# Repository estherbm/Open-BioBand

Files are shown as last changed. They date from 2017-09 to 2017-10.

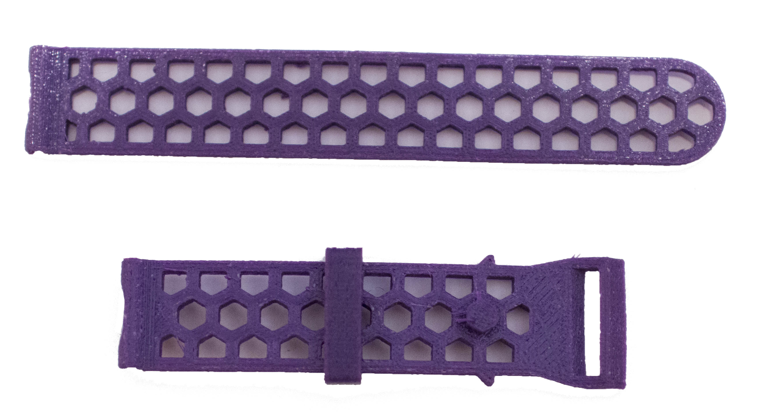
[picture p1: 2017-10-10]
Images/Testing/3.jpg

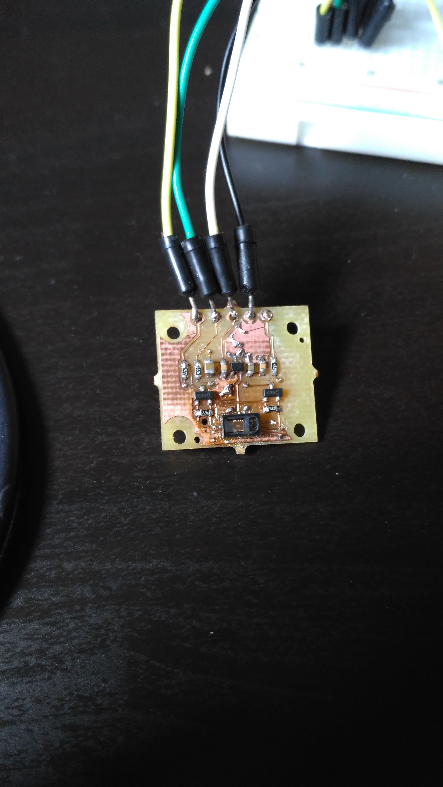
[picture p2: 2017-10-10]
Images/Testing/MAX30101.jpeg

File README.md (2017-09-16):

# Open-BioBand

    Open BioBand is a biometric Open Source wristband with BLE (Bluetooth
    Low Energy) connectivity used to non-invasive monitorization of patients
    and their environment. It measure several parameters such as pulse, SPO2,
    body temperature, motion activity, pressure, humidity, temperature...

    It allow developers to investigate and learn about wearables and biometric 
    sensors and artists to create new biological performances and projects.
    
    Created as final thesis Industrial Engineering project.

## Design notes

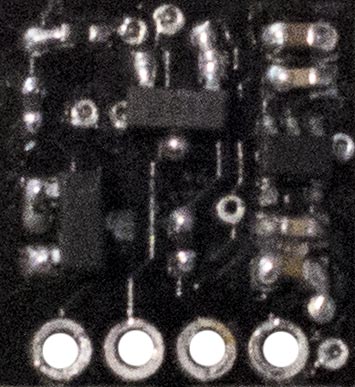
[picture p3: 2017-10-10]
Images/PCBs/MAX30101-B.jpg

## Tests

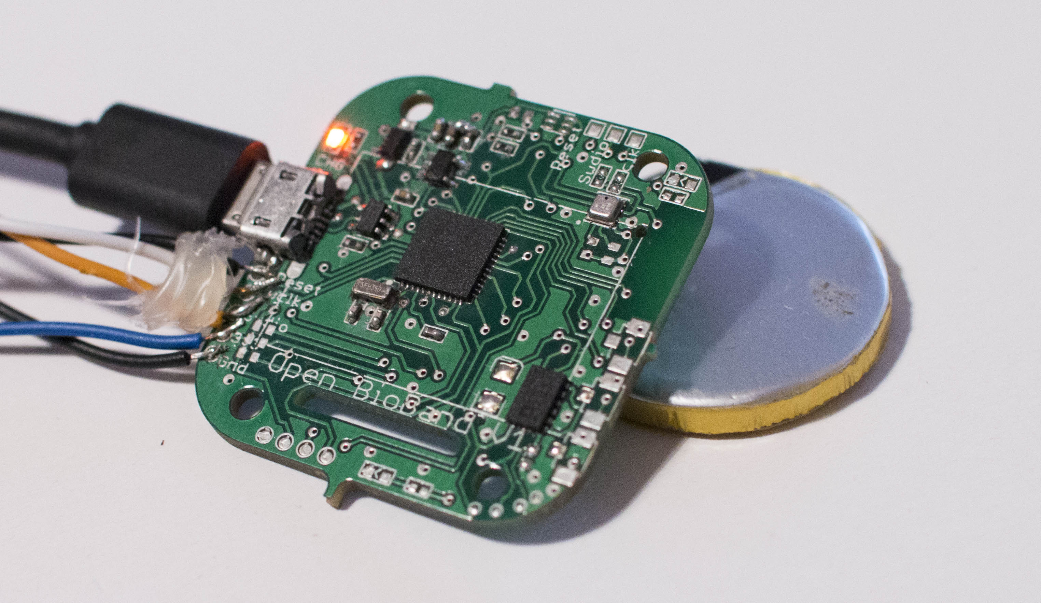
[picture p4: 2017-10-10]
Images/Testing/USBcharging.jpg

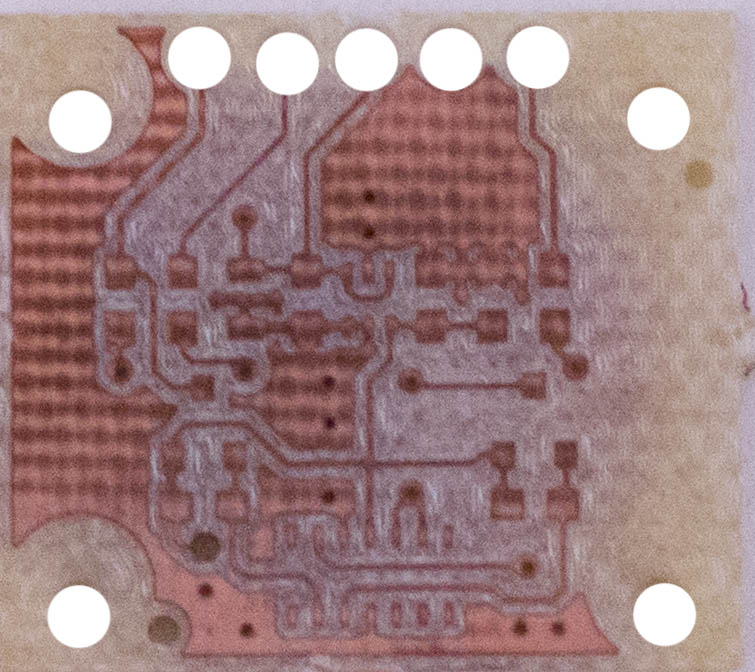
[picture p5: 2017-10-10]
Images/Testing/MAX30101-B_test.jpg

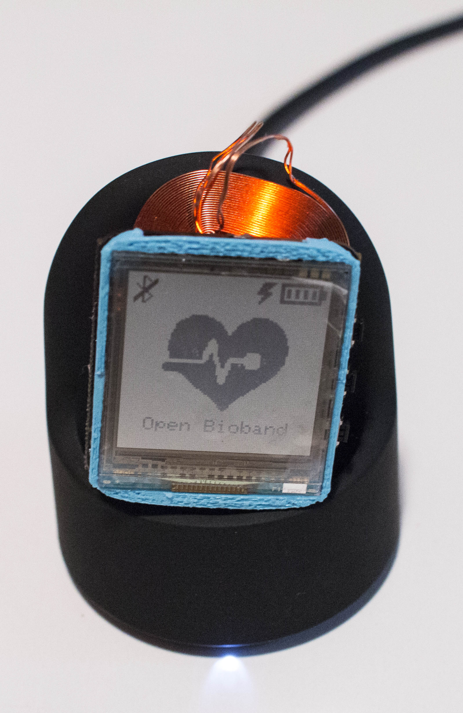
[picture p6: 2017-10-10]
Images/Testing/QiCharging.jpg

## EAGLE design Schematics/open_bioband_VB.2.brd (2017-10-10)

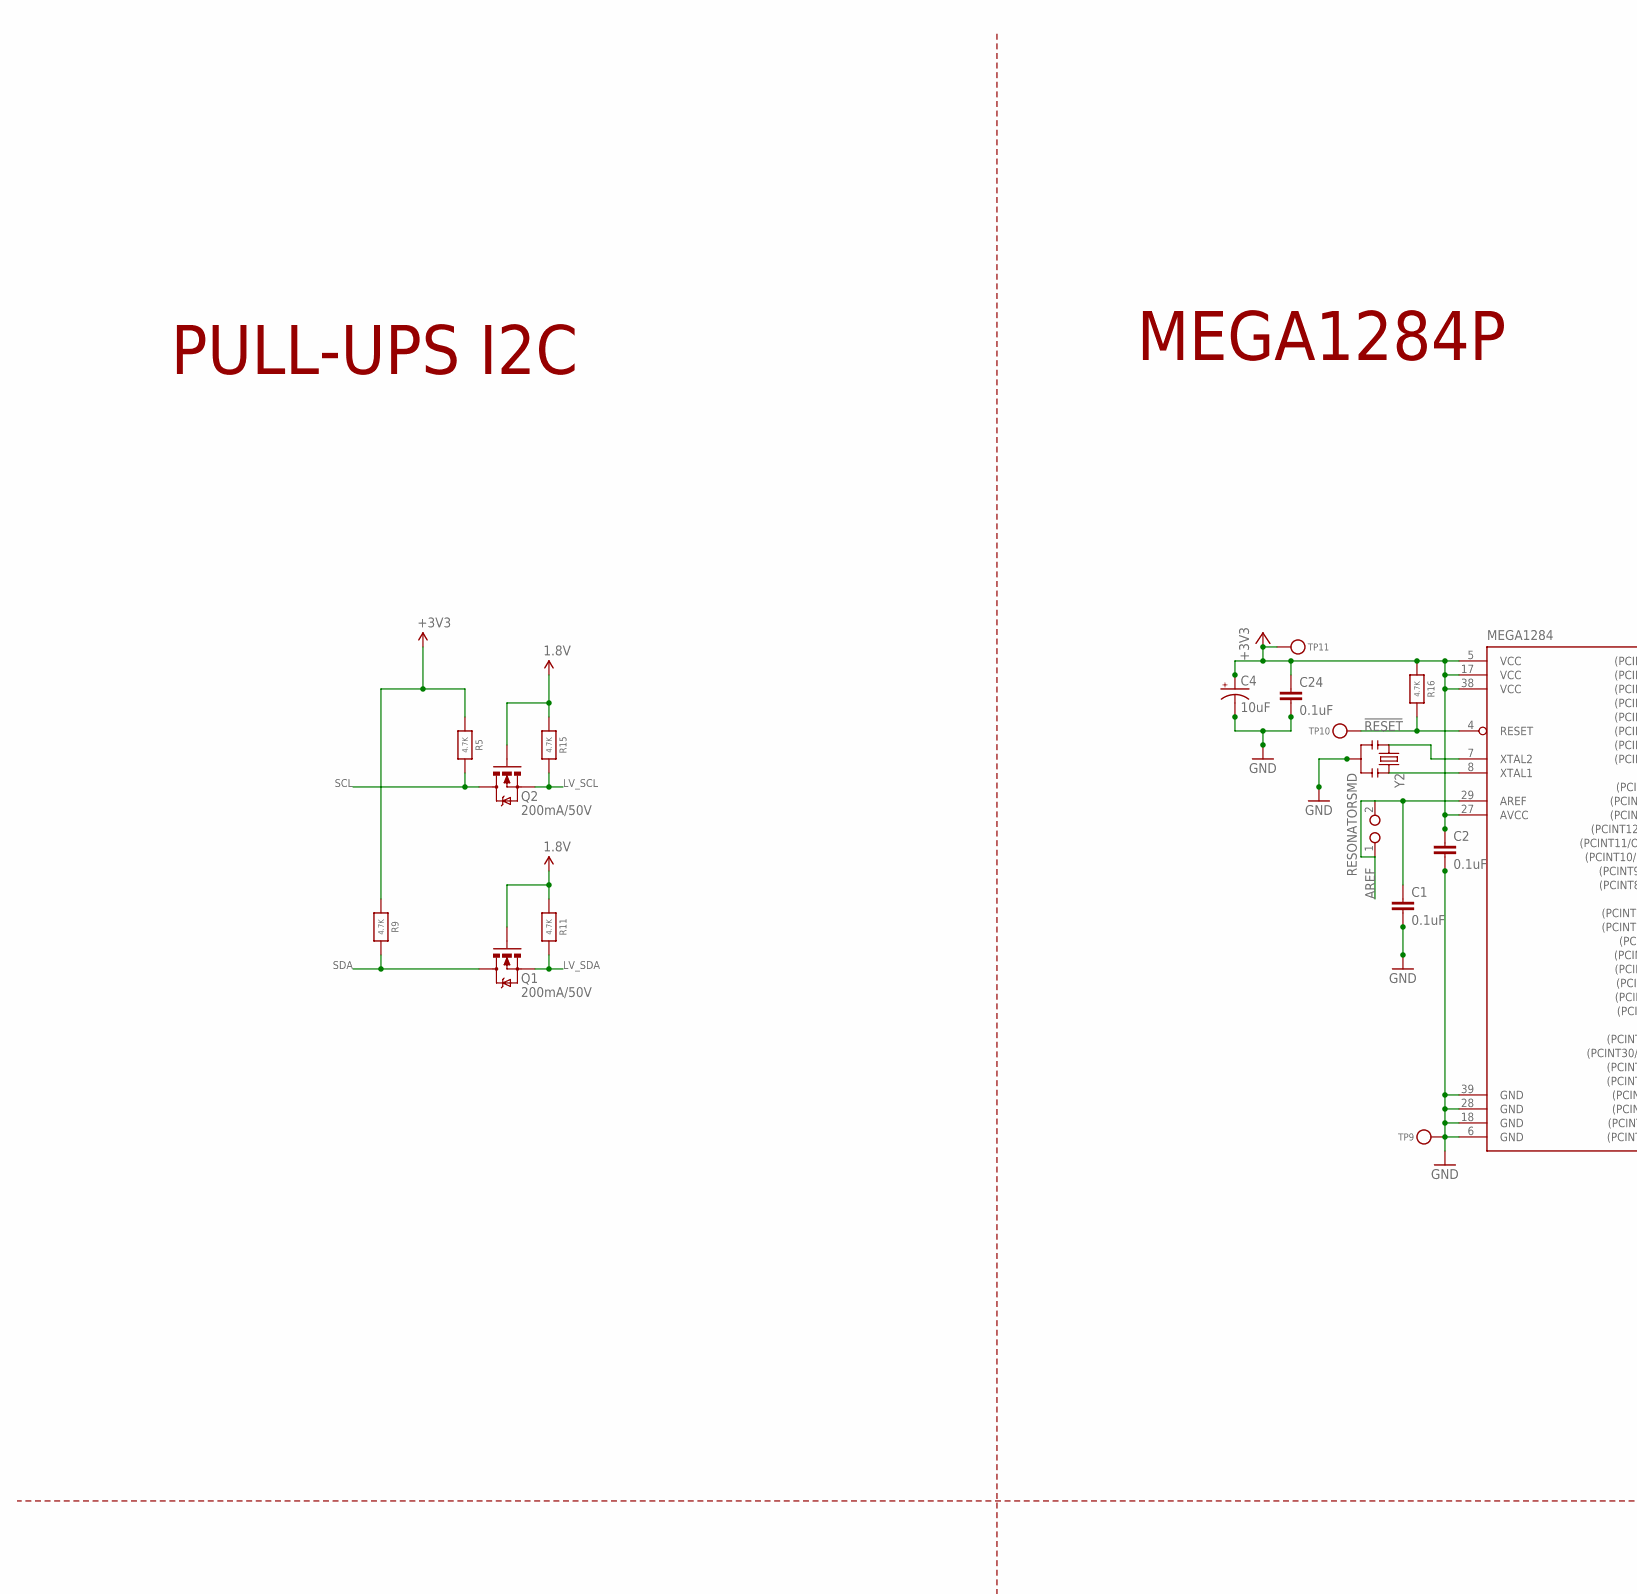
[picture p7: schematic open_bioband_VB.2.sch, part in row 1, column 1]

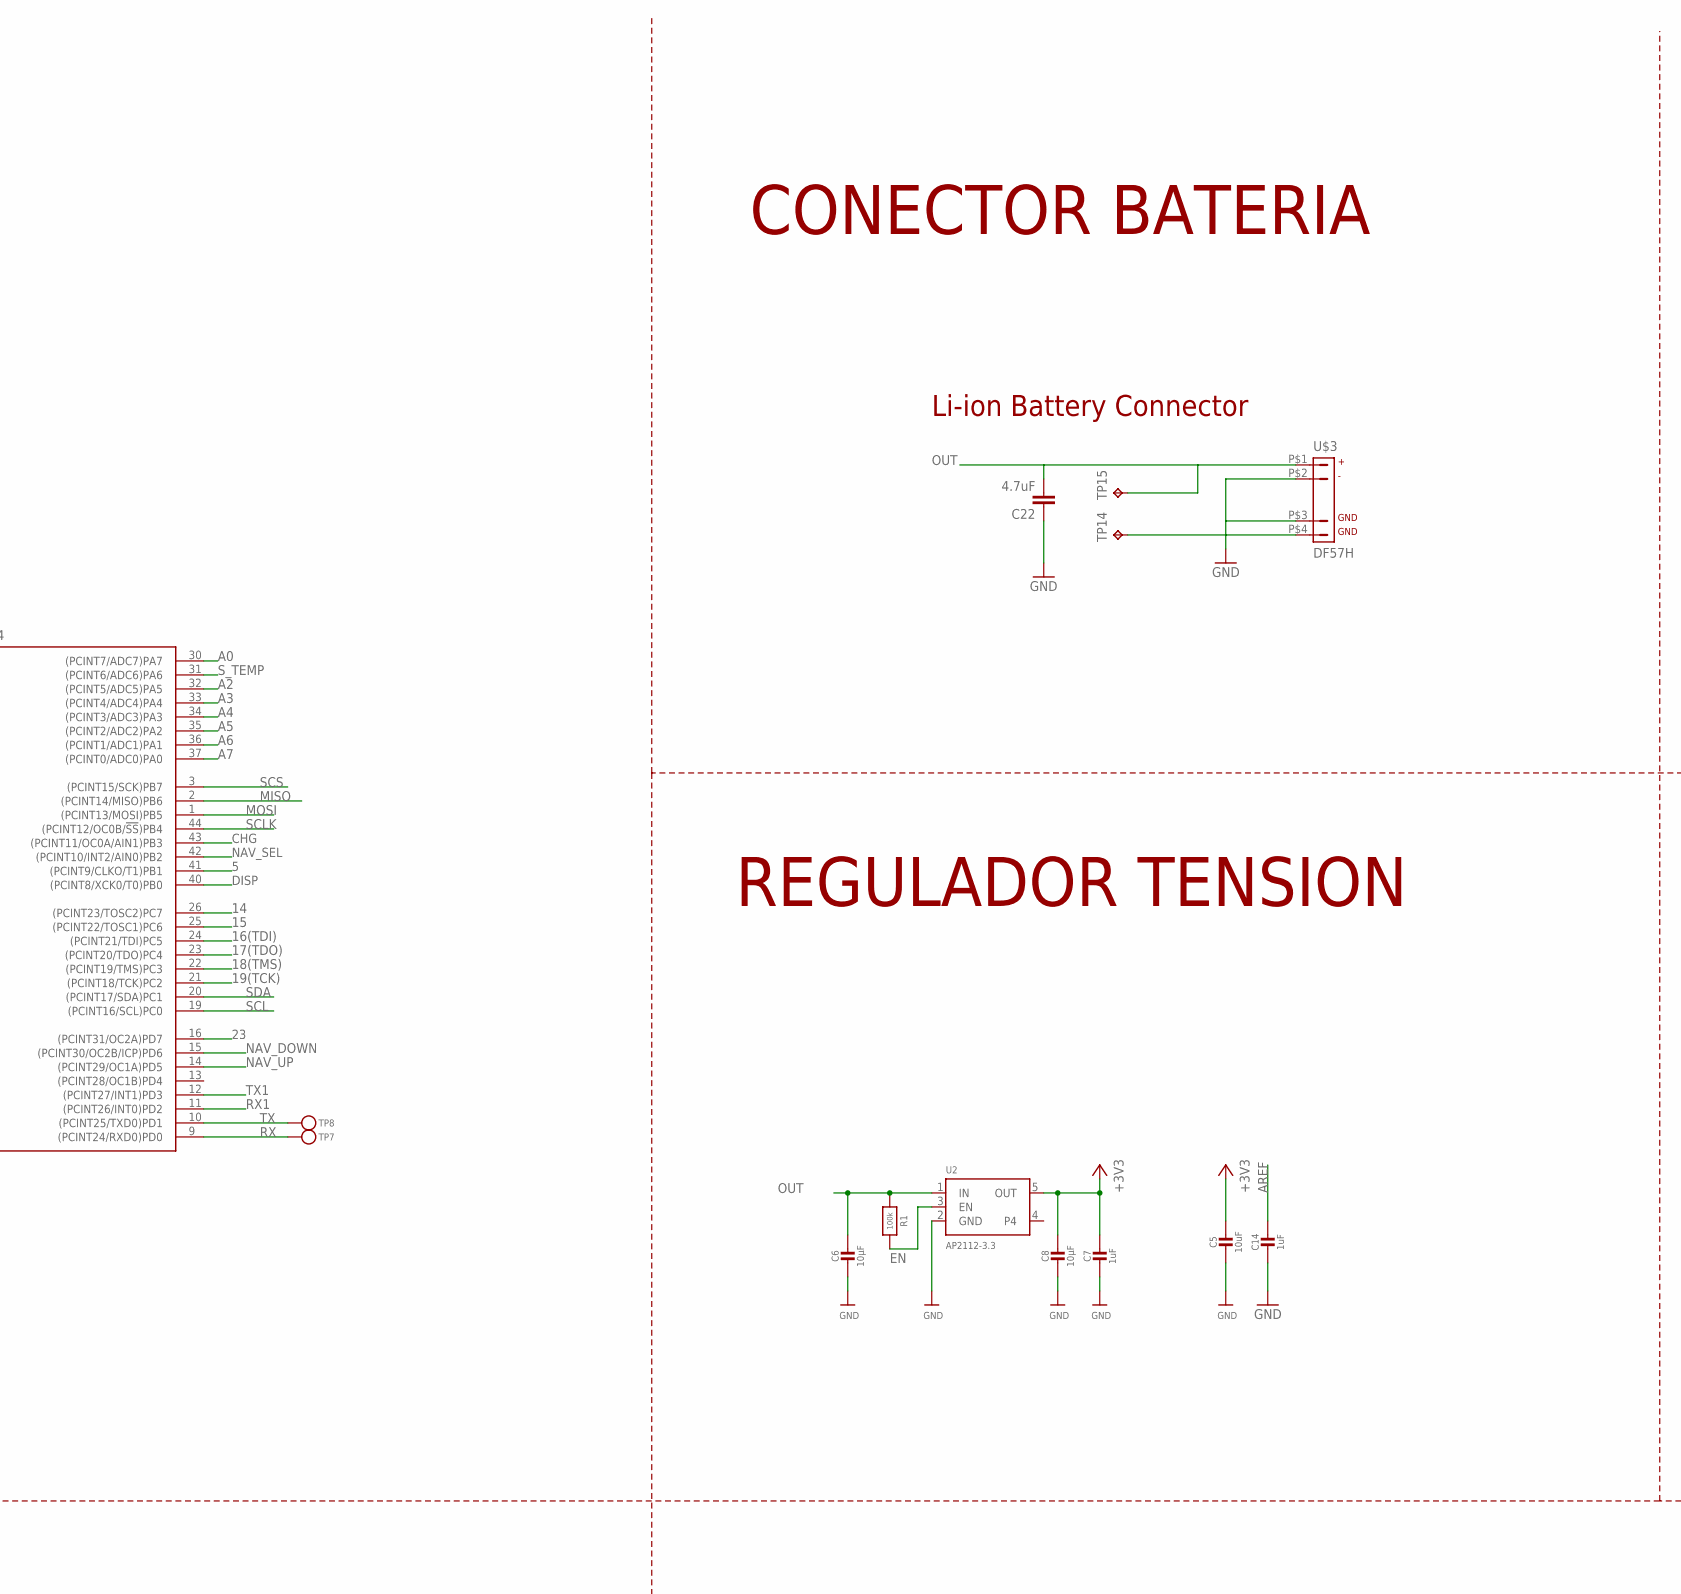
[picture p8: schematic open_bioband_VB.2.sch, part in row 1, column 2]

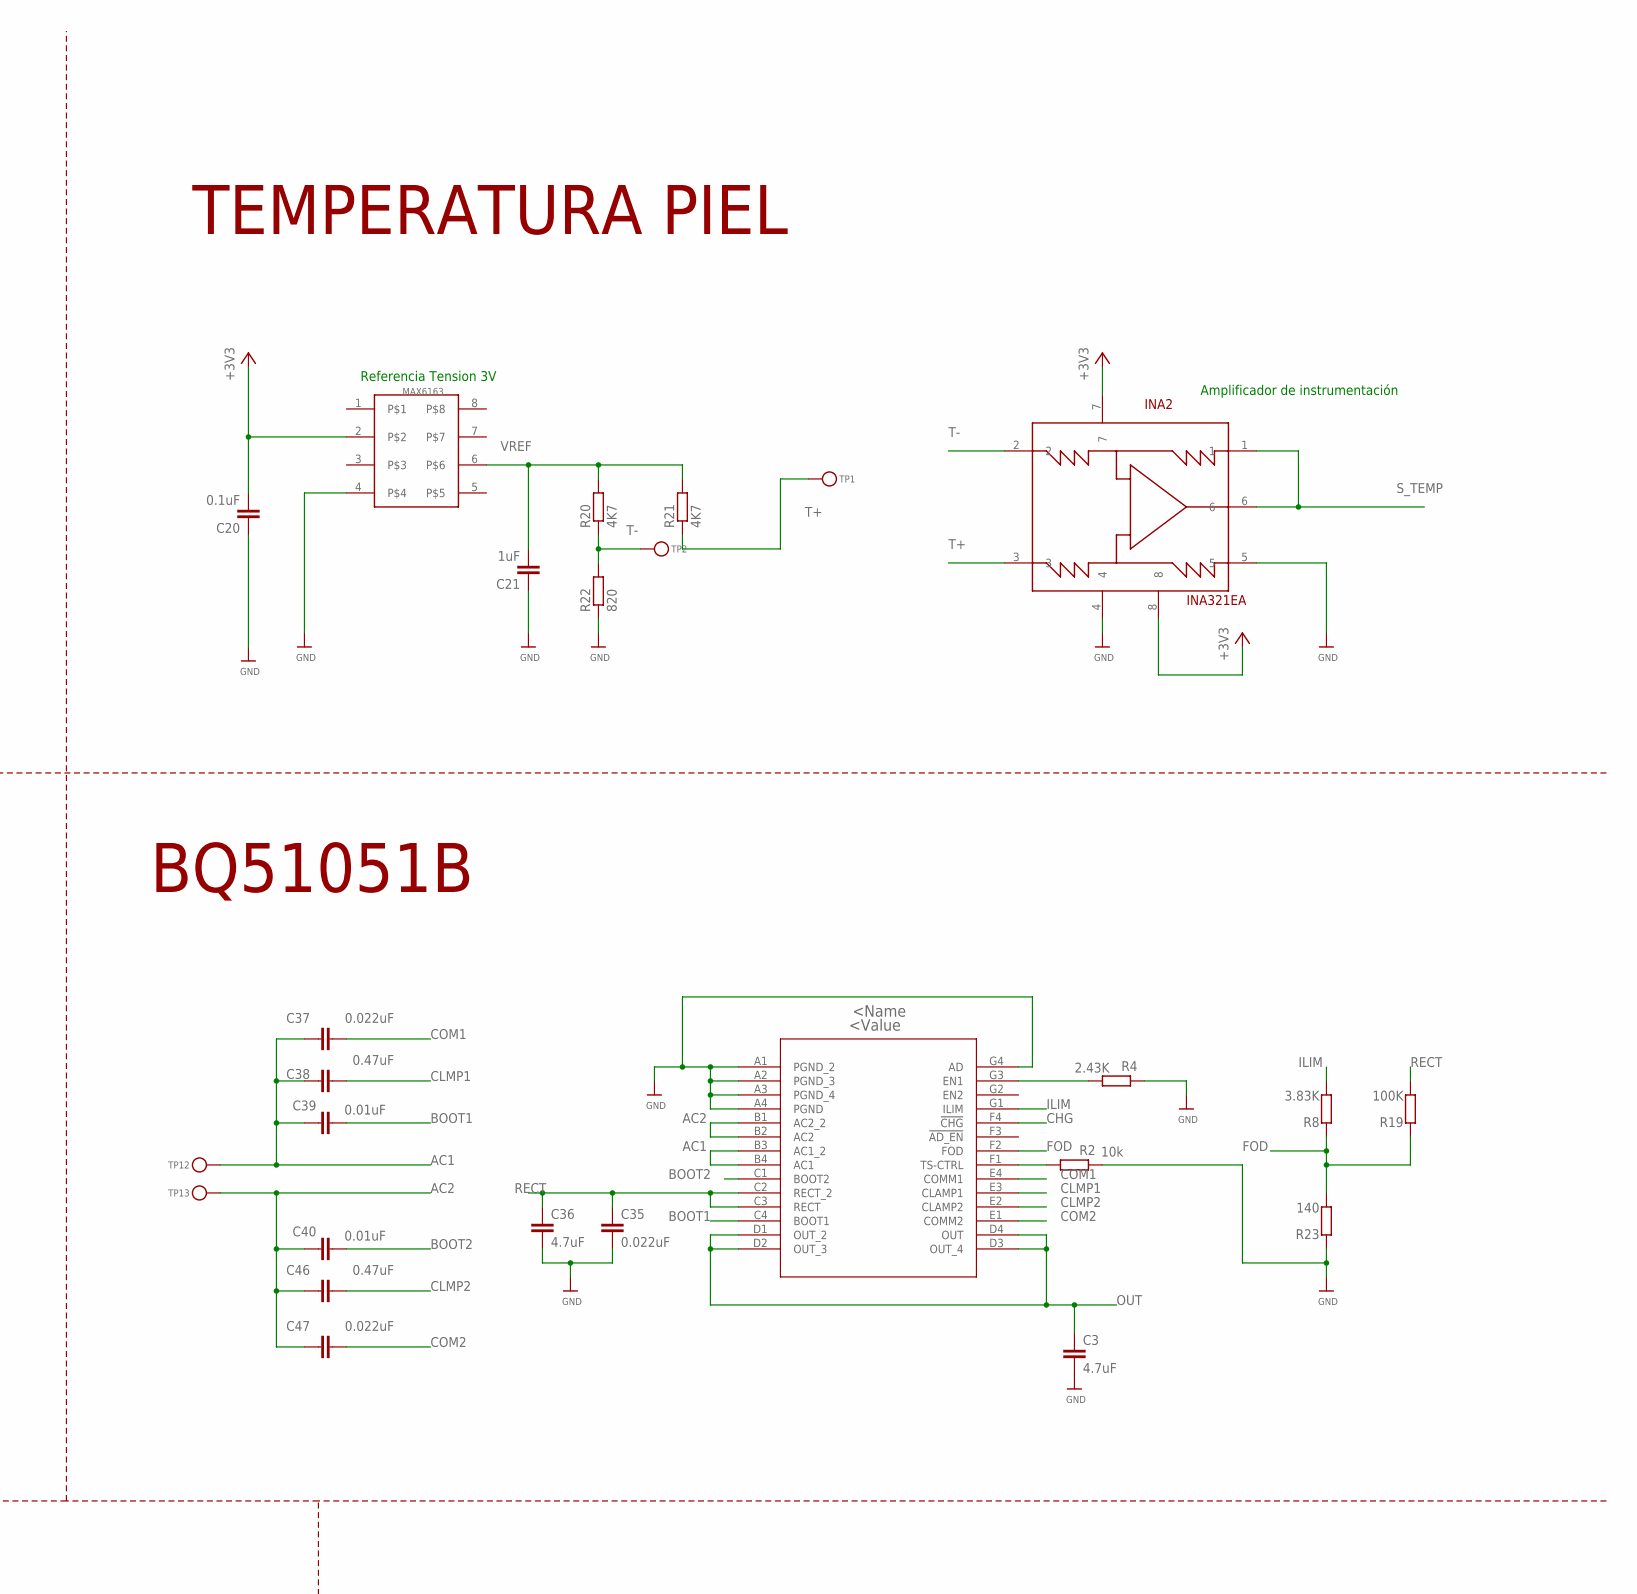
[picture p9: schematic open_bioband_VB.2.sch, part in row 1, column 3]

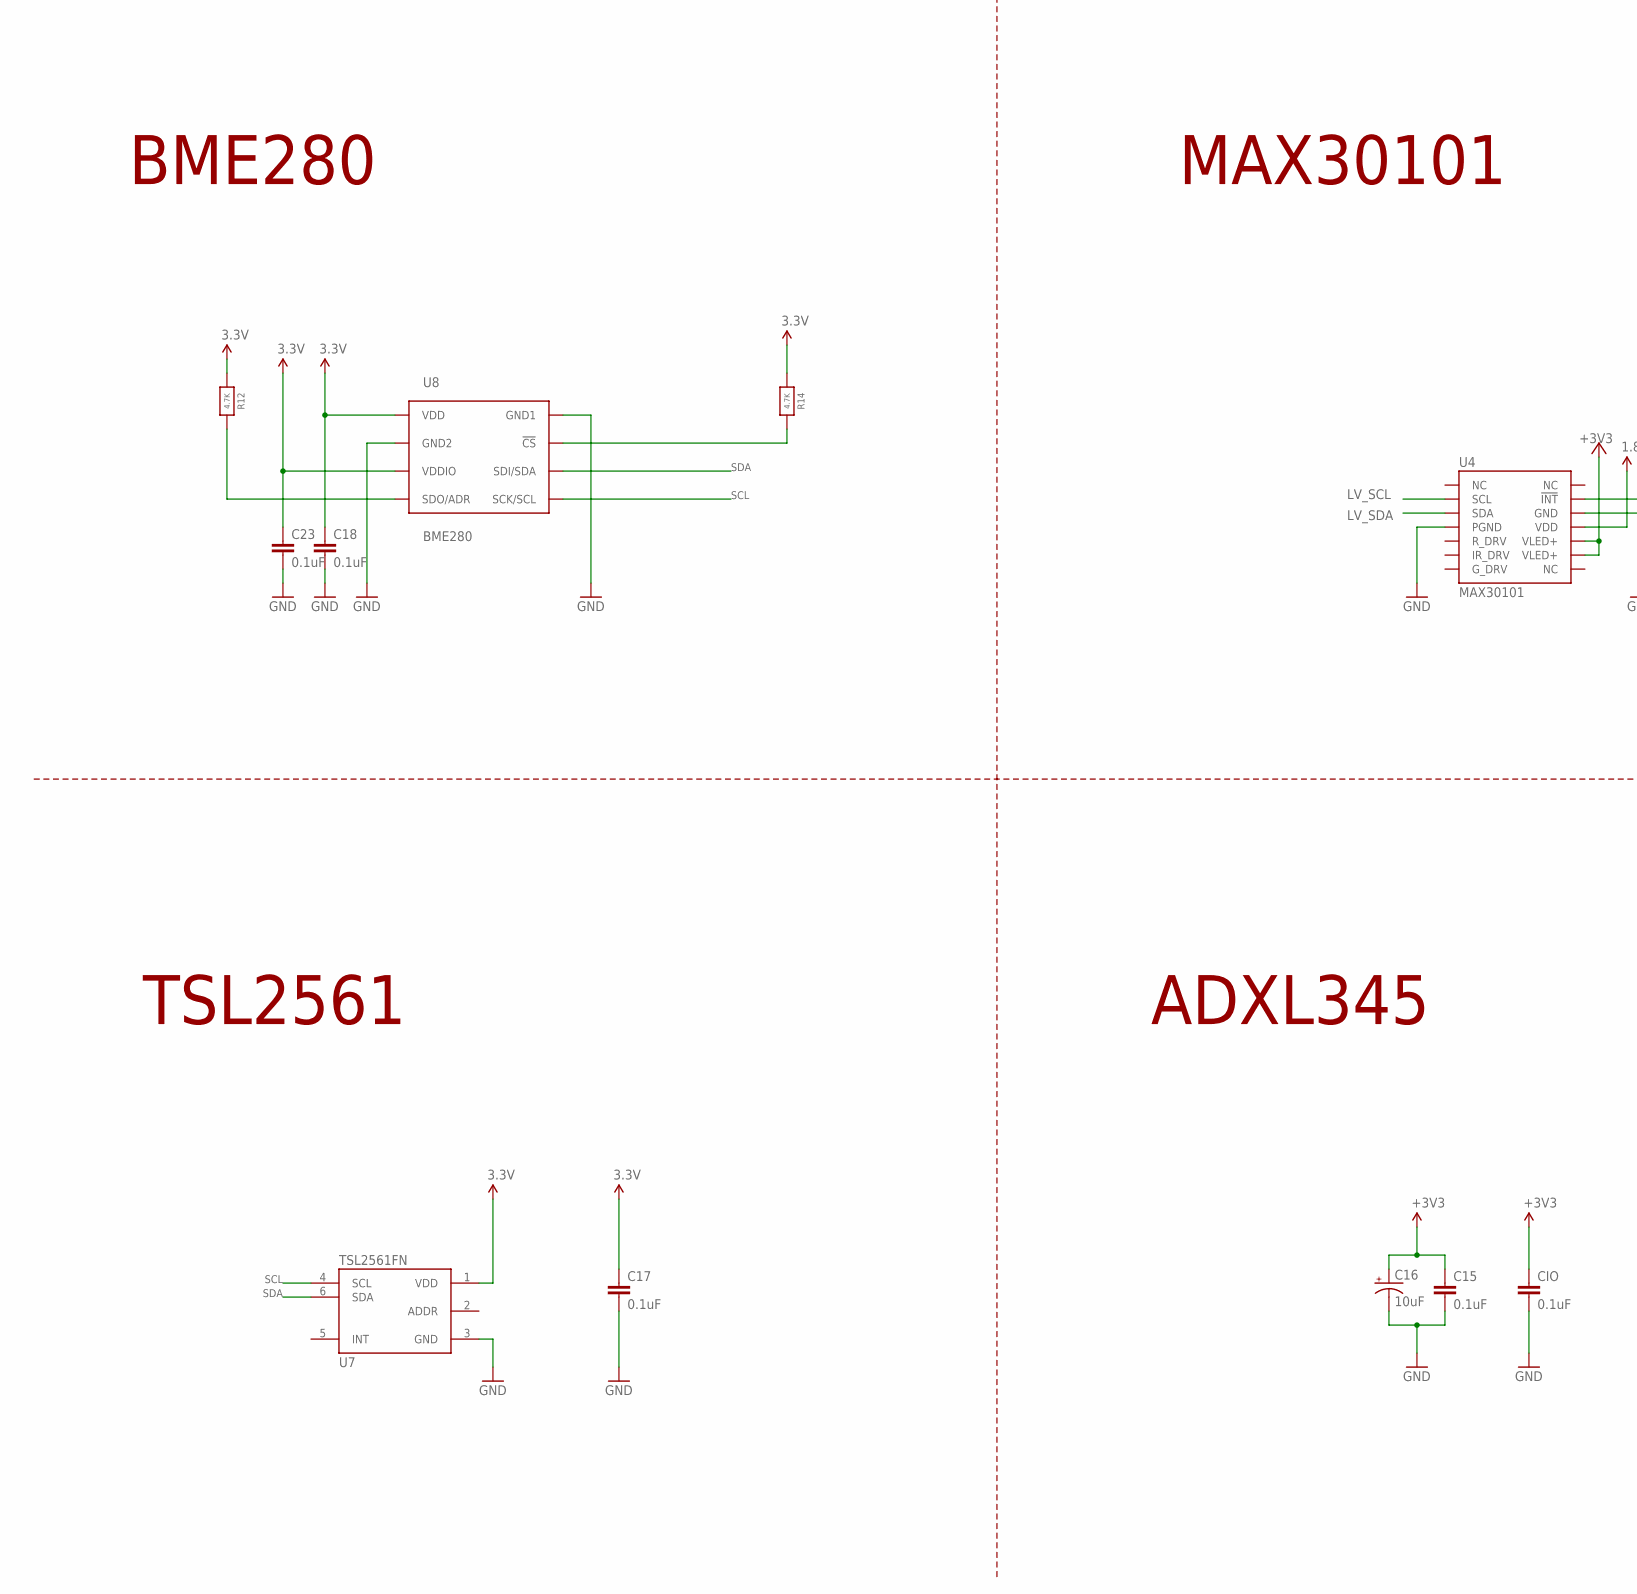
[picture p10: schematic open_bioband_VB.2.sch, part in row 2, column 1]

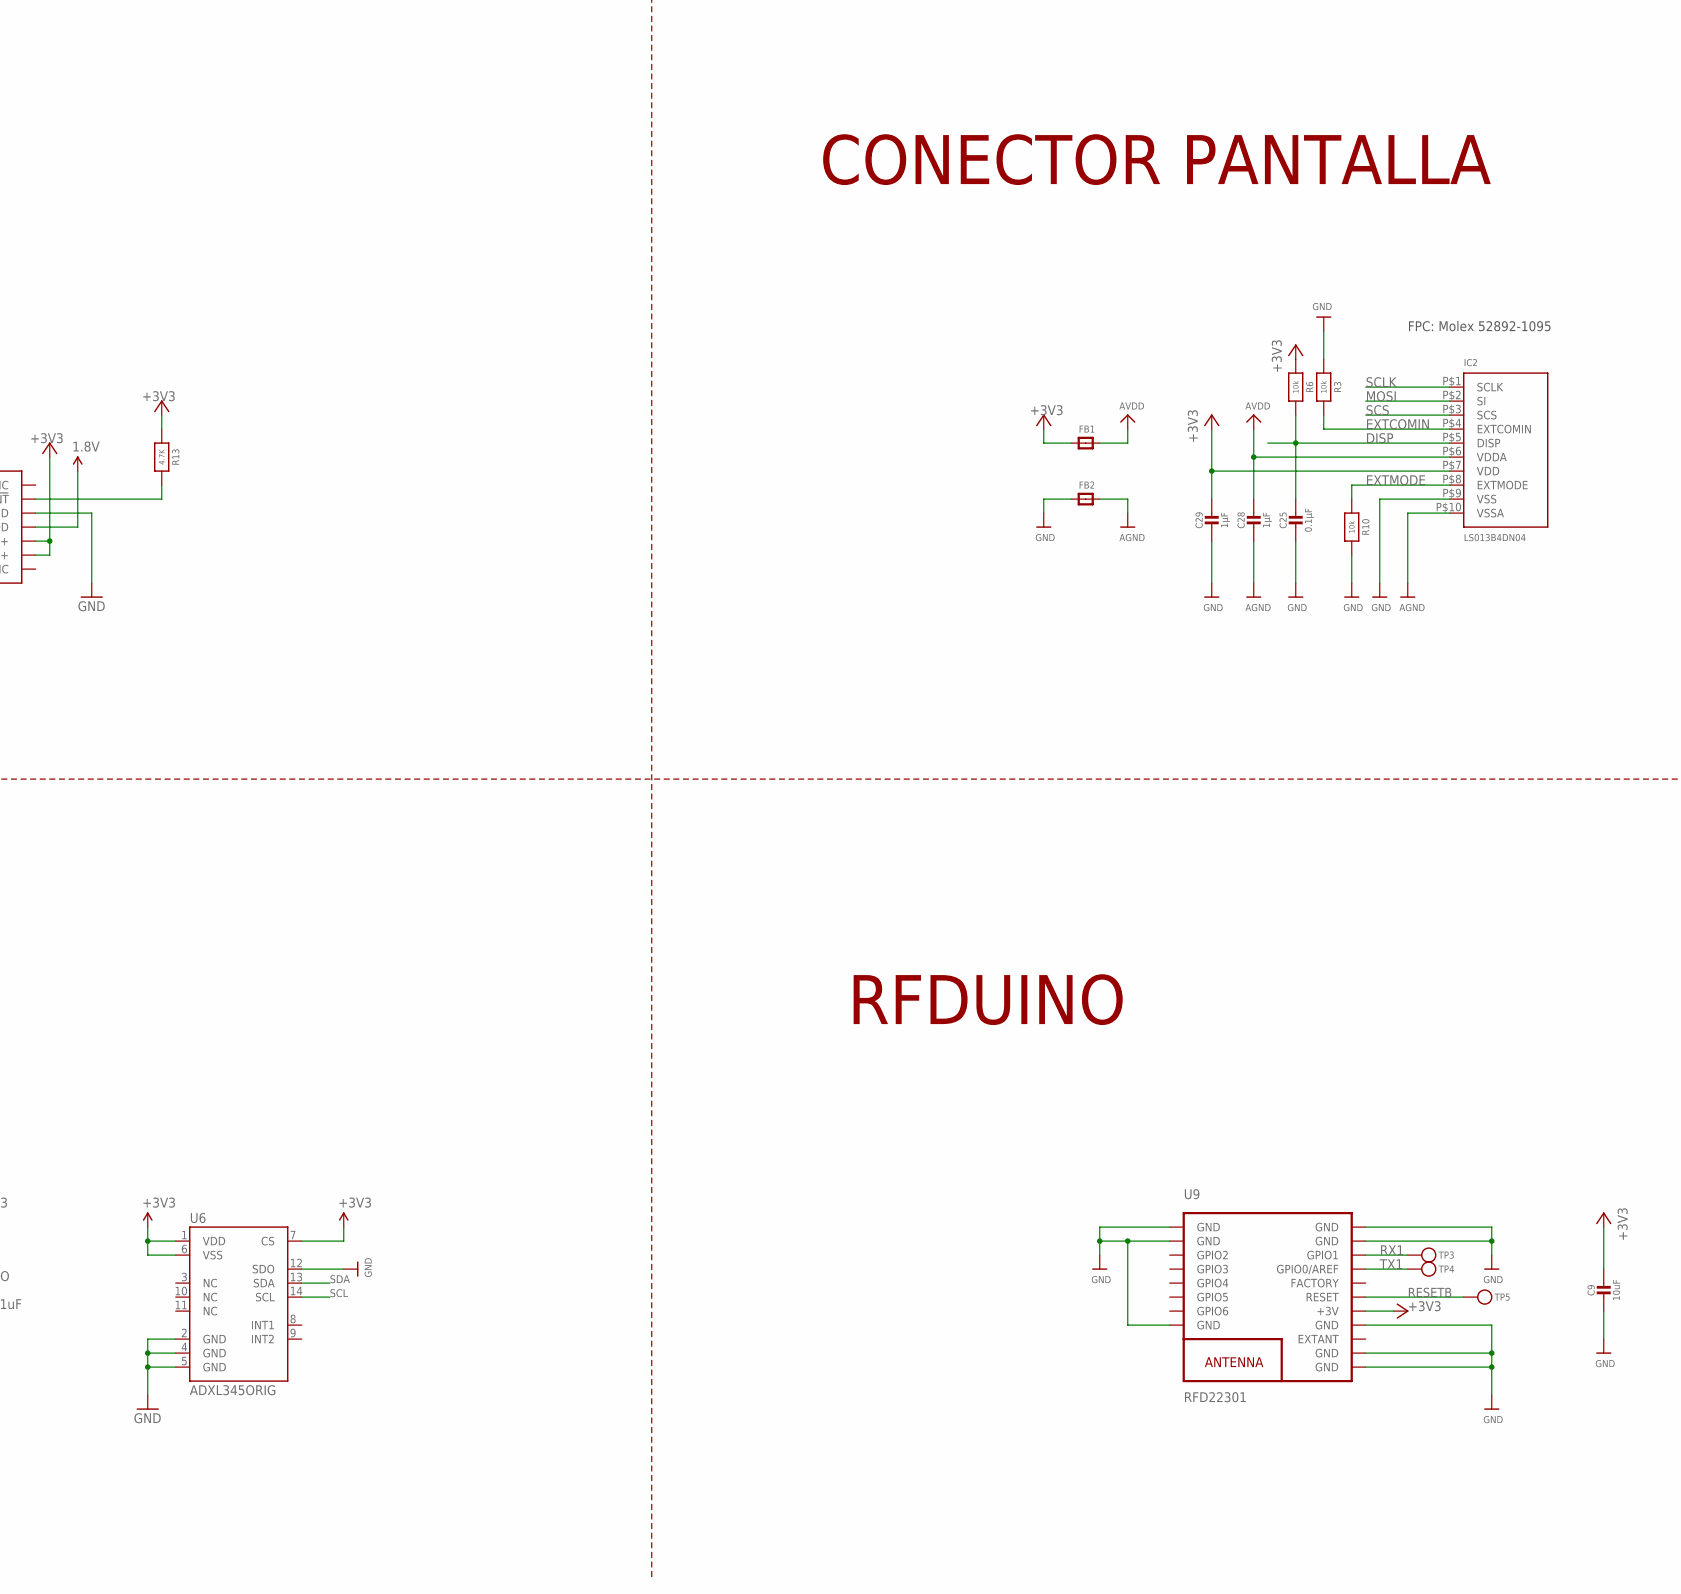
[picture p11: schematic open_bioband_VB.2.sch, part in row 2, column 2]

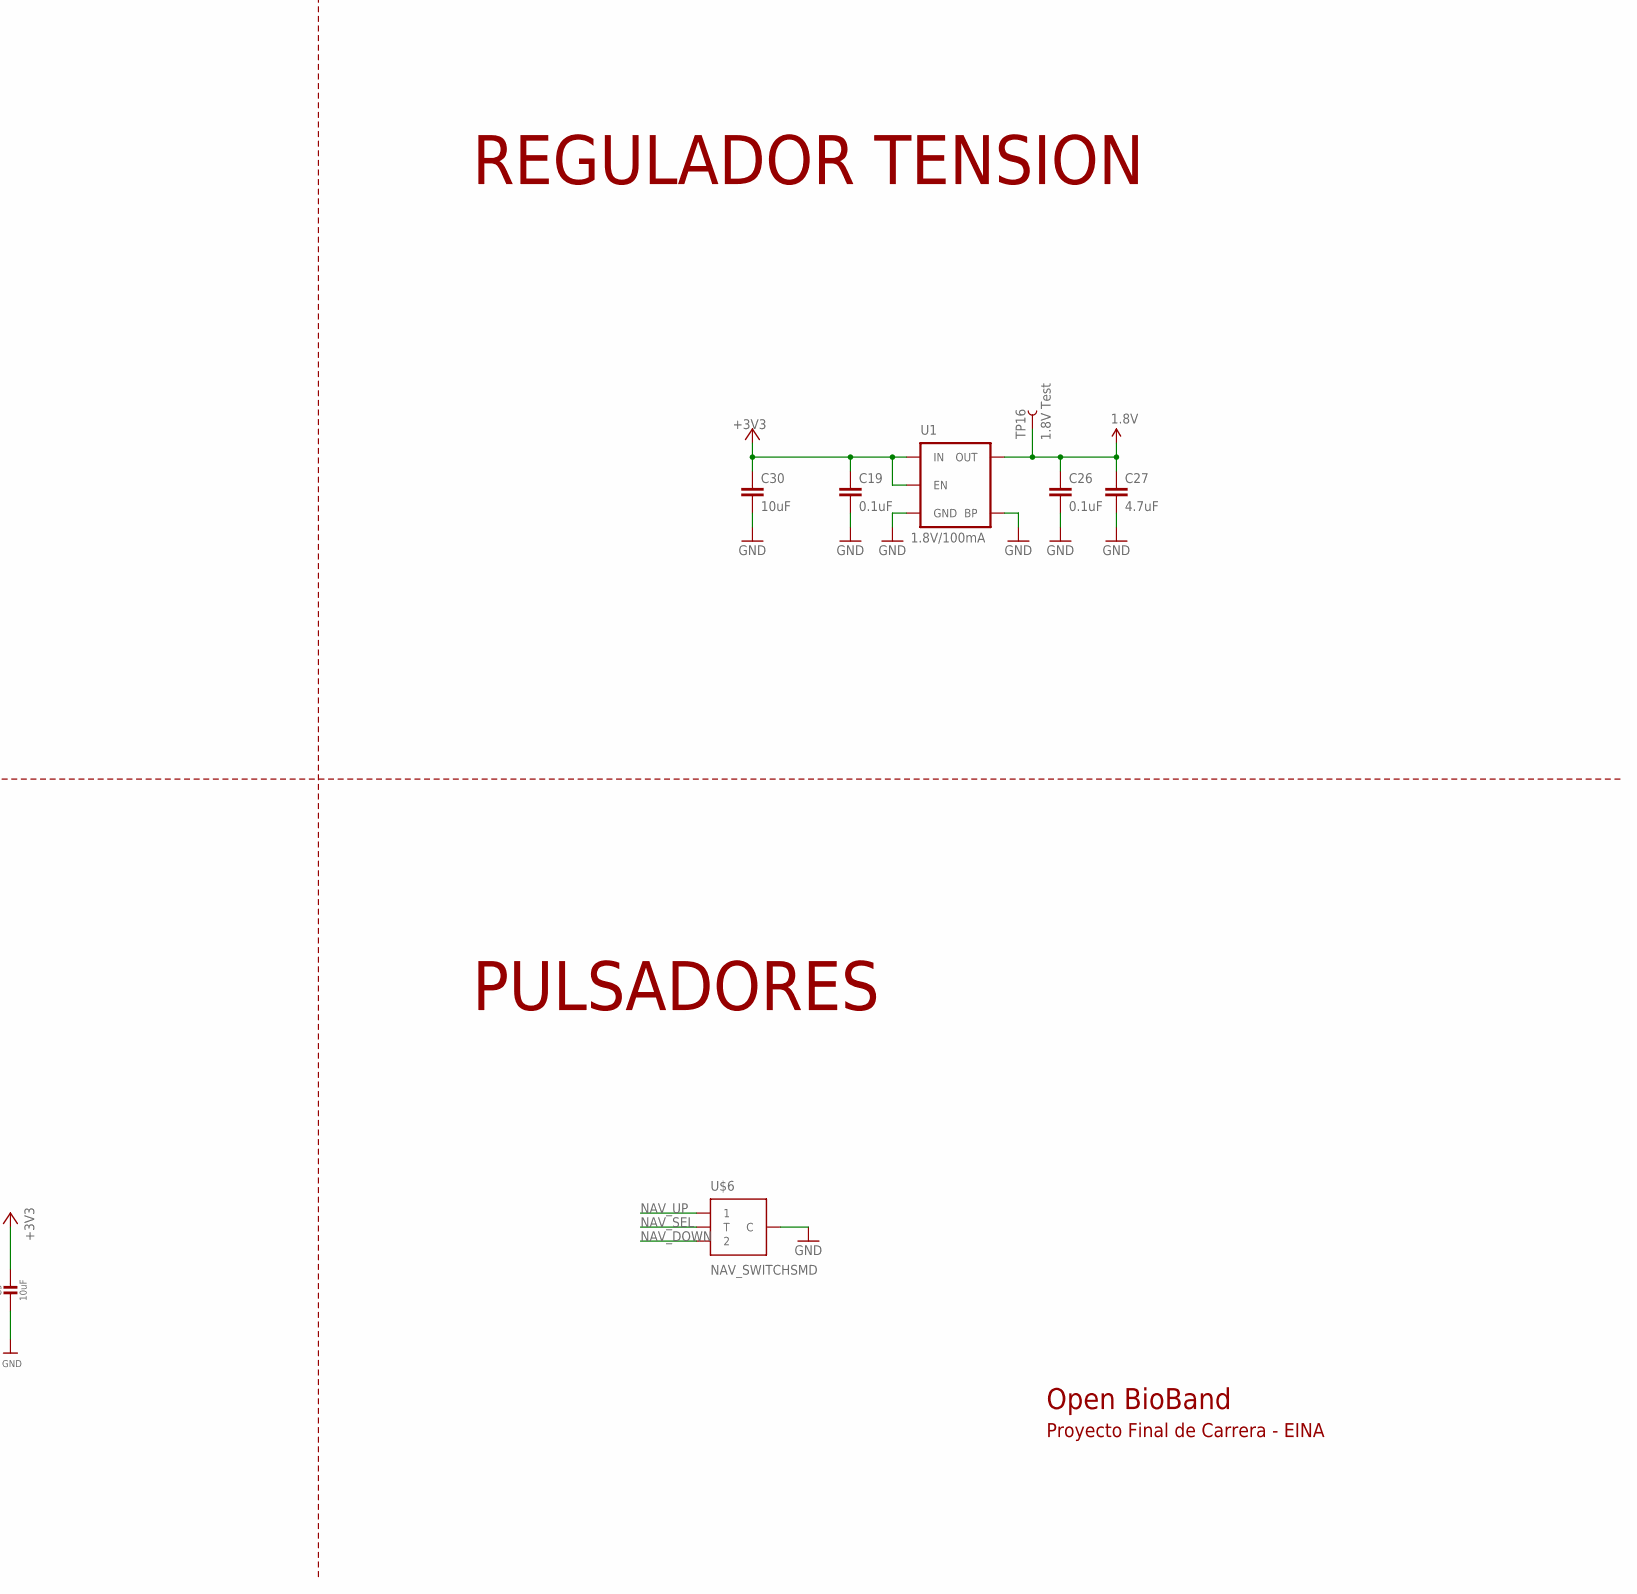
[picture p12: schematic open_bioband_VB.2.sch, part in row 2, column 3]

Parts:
C1, C2, C15, C17, C18, C19, C23, C24, C26: 0.1uF; 0402-CAP
C3, C22, C36: 4.7uF; C0402
C4, C16: 10uF; EIA3216
C5, C9: 10uF; _0402
C6, C8: 10µF; _0402
C7, C14: 1uF; _0402
C20: 0.1uF; C0402
C21: 1uF; C0402
C25: 0.1µF; _0402
C27: 4.7uF; 0402-CAP
C28, C29: 1µF; _0402
C30: 10uF; 0402-CAP
C35, C37, C47: 0.022uF; C0402
C38, C46: 0.47uF; C0402
C39, C40: 0.01uF; C0402
CIO: 0.1uF; 0402-CAP
FB1, FB2: FERRITE_0402; _0402
IC2: LS013B4DN04; FPC_10PIN_52892-1095
INA2: INA321EA; MSOP08
MAX1: MAX6163; SO08
MEGA1284: ATMEGA644A; TQFP44
Q1, Q2: 200mA/50V; SOT23-3
R1: 100k; _0402
R2: 10k; R0402
R3, R6, R10: 10k; _0402
R4: 2.43K; R0402
R5, R9, R11, R12, R13, R14, R15, R16: 4.7K; _0402
R8: 3.83K; R0402
R19: 100K; R0402
R20, R21: 4K7; R0402
R22: 820; R0402
R23: 140; R0402
TP1, TP2, TP3, TP4, TP5, TP7, TP8, TP9, TP10, TP11, TP12, TP13: TESTPOINTROUND1.5MM; TESTPOINT_ROUND_1.5MM
TP14, TP15: TPB1,27; B1,27
TP16: 1.8V Test; PAD.03X.04
U1: 1.8V/100mA; SC70
U2: AP2112-3.3; SOT23-5
U3: BQ51003YFPT; YFP28
U4: MAX30101; OLGA-14
U6: ADXL345ORIG; LGA14
U7: TSL2561FN; FN-6
U8: BME280; BME280_LGA
U9: RFD22301
U$3: DF57H; DF57H-2P
U$5: JUMPER1-1
U$6: NAV_SWITCHSMD; NAV_SWITCH
Y2: RESONATORSMD; RESONATOR-SMD

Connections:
1.8V: C26.1, C27.1, Q1.1 (G), Q2.1 (G), R11.1, R15.1, TP16.P$1, U1.5 (OUT), U4.11 (VDD)
5: MEGA1284.41 ((PCINT9/CLKO/T1)PB1)
14: MEGA1284.26 ((PCINT23/TOSC2)PC7)
15: MEGA1284.25 ((PCINT22/TOSC1)PC6)
16(TDI): MEGA1284.24 ((PCINT21/TDI)PC5)
17(TDO): MEGA1284.23 ((PCINT20/TDO)PC4)
18(TMS): MEGA1284.22 ((PCINT19/TMS)PC3)
19(TCK): MEGA1284.21 ((PCINT18/TCK)PC2)
23: MEGA1284.16 ((PCINT31/OC2A)PD7)
!CS: R14.2, U8.P$2 (!CS)
!INT: R13.2, U4.13 (!INT)
!RESET: MEGA1284.4 (RESET), R16.2, TP10.P$1
+3V3: C2.1, C4.A (+), C5.1, C7.1, C8.1, C9.1, C15.1, C16.A (+), C17.1, C19.1, C20.2, C24.1, C29.1, C30.1, CIO.1, FB1.1, IC2.P$7 (VDD), INA2.7, INA2.8, MAX1.2, MEGA1284.5 (VCC), MEGA1284.17 (VCC), MEGA1284.27 (AVCC), MEGA1284.38 (VCC), R5.1, R6.1, R9.1, R13.1, R16.1, TP11.P$1, U1.1 (IN), U1.3 (EN), U2.5 (OUT), U4.9 (VLED+), U4.10 (VLED+), U6.1 (VDD), U6.6 (VSS), U6.7 (CS), U7.1 (VDD), U9.13 (+3V)
A0: MEGA1284.30 ((PCINT7/ADC7)PA7)
A2: MEGA1284.32 ((PCINT5/ADC5)PA5)
A3: MEGA1284.33 ((PCINT4/ADC4)PA4)
A4: MEGA1284.34 ((PCINT3/ADC3)PA3)
A5: MEGA1284.35 ((PCINT2/ADC2)PA2)
A6: MEGA1284.36 ((PCINT1/ADC1)PA1)
A7: MEGA1284.37 ((PCINT0/ADC0)PA0)
AC1: C37.1, C38.1, C39.1, TP12.P$1, U3.B3 (AC1_2), U3.B4 (AC1)
AC2: C40.1, C46.1, C47.1, TP13.P$1, U3.B1 (AC2_2), U3.B2 (AC2)
AGND: C28.2, FB2.2, IC2.P$10 (VSSA)
AREF: C1.1, C14.1, MEGA1284.29 (AREF), U$5.1, U$5.2
AVDD: C28.1, FB1.2, IC2.P$6 (VDDA)
BOOT1: C39.2, U3.C4 (BOOT1)
BOOT2: C40.2, U3.C1 (BOOT2)
CHG: MEGA1284.43 ((PCINT11/OC0A/AIN1)PB3), U3.F4 (!CHG)
CLMP1: C38.2, U3.E3 (CLAMP1)
CLMP2: C46.2, U3.E2 (CLAMP2)
COM1: C37.2, U3.E4 (COMM1)
COM2: C47.2, U3.E1 (COMM2)
DISP: C25.1, IC2.P$5 (DISP), MEGA1284.40 ((PCINT8/XCK0/T0)PB0), R6.2
EN: R1.2, U2.3 (EN)
EXTCOMIN: IC2.P$4 (EXTCOMIN), R3.2
EXTMODE: IC2.P$8 (EXTMODE), R10.1
FOD: R8.1, R19.1, R23.2, U3.F2 (FOD)
GND: C1.2, C2.2, C3.2, C4.C (-), C5.2, C6.2, C7.2, C8.2, C9.2, C14.2, C15.2, C16.C (-), C17.2, C18.2, C19.2, C20.1, C21.1, C22.1, C23.2, C24.2, C25.2, C26.2, C27.2, C29.2, C30.2, C35.2, C36.2, CIO.2, FB2.1, IC2.P$9 (VSS), INA2.4, INA2.5, MAX1.4, MEGA1284.6 (GND), MEGA1284.18 (GND), MEGA1284.28 (GND), MEGA1284.39 (GND), R2.2, R3.1, R4.2, R10.2, R22.1, R23.1, TP9.P$1, TP14.TP, U1.2 (GND), U1.4 (BP), U2.2 (GND), U3.A1 (PGND_2), U3.A2 (PGND_3), U3.A3 (PGND_4), U3.A4 (PGND), U3.G4 (AD), U4.4 (PGND), U4.12 (GND), U6.2 (GND), U6.4 (GND), U6.5 (GND), U6.12 (SDO), U7.3 (GND), U8.P$1 (GND1), U8.P$7 (GND2), U9.1 (GND), U9.2 (GND), U9.8 (GND), U9.9 (GND), U9.10 (GND), U9.12 (GND), U9.18 (GND), U9.19 (GND), U$3.P$2 (2), U$3.P$3 (5), U$3.P$4 (6), U$6.C, Y2.2
ILIM: R8.2, U3.G1 (ILIM)
LV_SCL: Q2.2 (S), R15.2, U4.2 (SCL)
LV_SDA: Q1.2 (S), R11.2, U4.3 (SDA)
MISO: MEGA1284.2 ((PCINT14/MISO)PB6)
MOSI: IC2.P$2 (SI), MEGA1284.1 ((PCINT13/MOSI)PB5)
unnamed: MEGA1284.7 (XTAL2), Y2.1
unnamed: R4.1, U3.G3 (EN1)
unnamed: MEGA1284.8 (XTAL1), Y2.3
unnamed: R2.1, U3.F1 (TS-CTRL)
NAV_DOWN: MEGA1284.15 ((PCINT30/OC2B/ICP)PD6), U$6.2
NAV_SEL: MEGA1284.42 ((PCINT10/INT2/AIN0)PB2), U$6.T
NAV_UP: MEGA1284.14 ((PCINT29/OC1A)PD5), U$6.1
OUT: C3.1, C6.1, C22.2, R1.1, TP15.TP, U2.1 (IN), U3.D1 (OUT_2), U3.D2 (OUT_3), U3.D3 (OUT_4), U3.D4 (OUT), U$3.P$1 (1)
RECT: C35.1, C36.1, R19.2, U3.C2 (RECT_2)
RESETB: TP5.P$1, U9.14 (RESET)
RX: MEGA1284.9 ((PCINT24/RXD0)PD0), TP7.P$1
RX1: MEGA1284.11 ((PCINT26/INT0)PD2), TP3.P$1, U9.17 (GPIO1)
SCL: MEGA1284.19 ((PCINT16/SCL)PC0), Q2.3 (D), R5.2, U6.14 (SCL), U7.4 (SCL), U8.P$4 (SCK/SCL)
SCLK: IC2.P$1 (SCLK), MEGA1284.44 ((PCINT12/OC0B/!SS!)PB4)
SCS: IC2.P$3 (SCS), MEGA1284.3 ((PCINT15/SCK)PB7)
SDA: MEGA1284.20 ((PCINT17/SDA)PC1), Q1.3 (D), R9.2, U6.13 (SDA), U7.6 (SDA), U8.P$3 (SDI/SDA)
SDO/ADR: R12.2, U8.P$5 (SDO/ADR)
S_TEMP: INA2.1, INA2.6, MEGA1284.31 ((PCINT6/ADC6)PA6)
T+: INA2.3, R21.1, TP1.P$1
T-: INA2.2, R20.1, R22.2, TP2.P$1
TX: MEGA1284.10 ((PCINT25/TXD0)PD1), TP8.P$1
TX1: MEGA1284.12 ((PCINT27/INT1)PD3), TP4.P$1, U9.16 (GPIO0/AREF)
VCC: C18.1, C23.1, R12.1, R14.1, U8.P$6 (VDDIO), U8.P$8 (VDD)
VREF: C21.2, MAX1.6, R20.2, R21.2

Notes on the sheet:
FPC: Molex 52892-1095
Referencia Tension 3V
Amplificador de instrumentación
Li-ion Battery Connector
Open BioBand
Proyecto Final de Carrera - EINA
TSL2561
ADXL345
RFDUINO
MAX30101
CONECTOR PANTALLA
BME280
REGULADOR TENSION
PULL-UPS I2C
MEGA1284P
CONECTOR BATERIA
BQ51051B
TEMPERATURA PIEL
PULSADORES

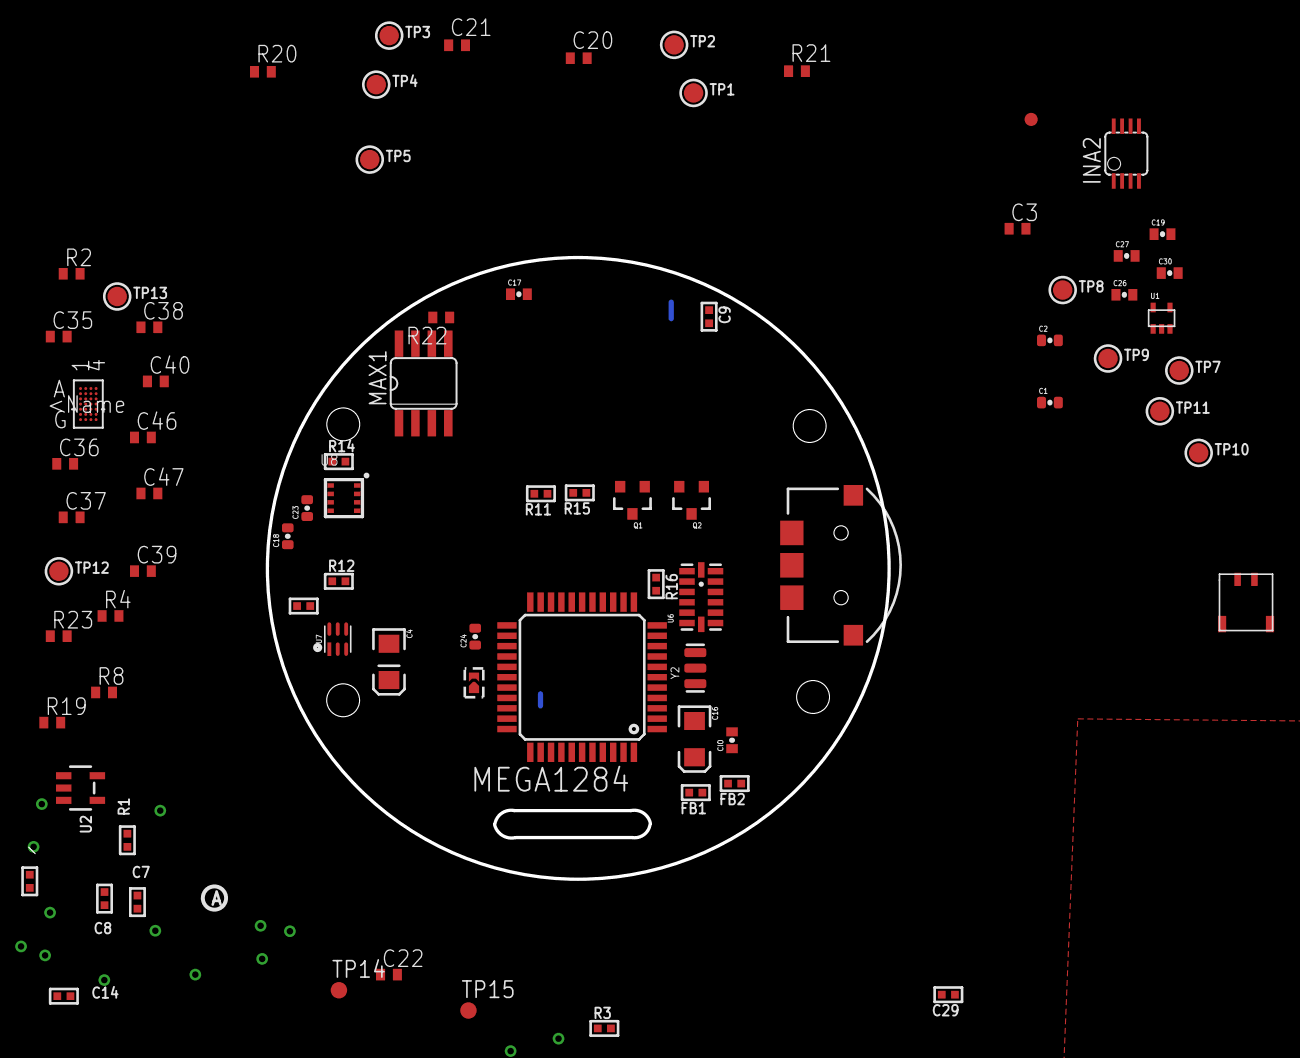
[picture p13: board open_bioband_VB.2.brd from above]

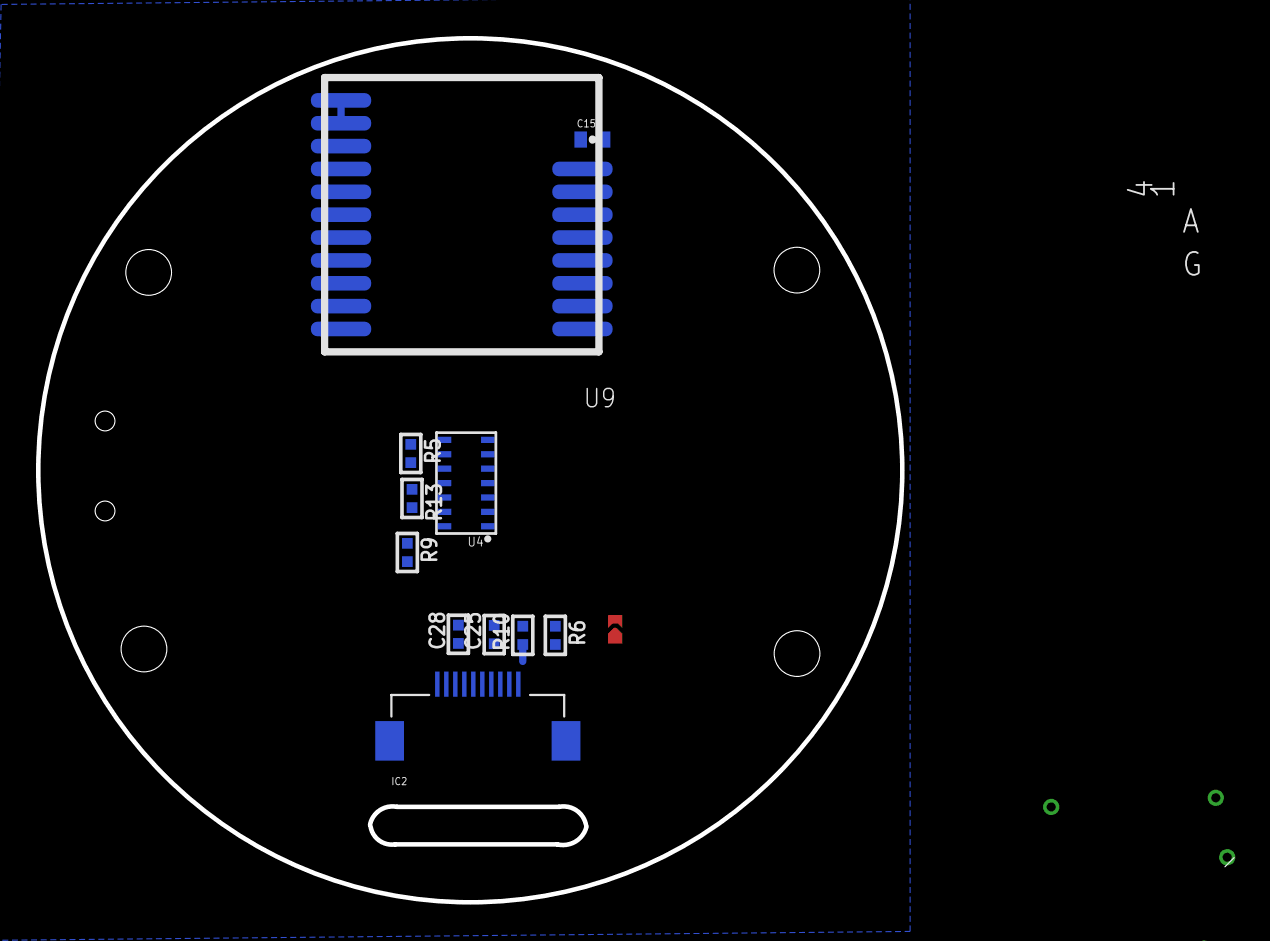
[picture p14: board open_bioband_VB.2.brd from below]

Board: 2 copper layers, 91 parts (11 on the bottom side), 51 nets.

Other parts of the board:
U$25: PCBFEAT-REV-040

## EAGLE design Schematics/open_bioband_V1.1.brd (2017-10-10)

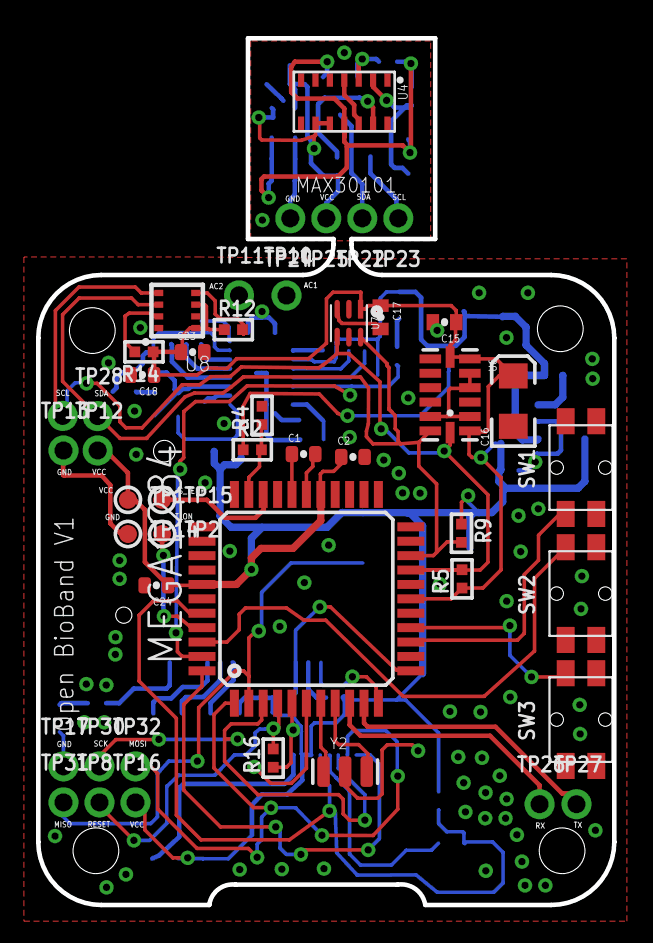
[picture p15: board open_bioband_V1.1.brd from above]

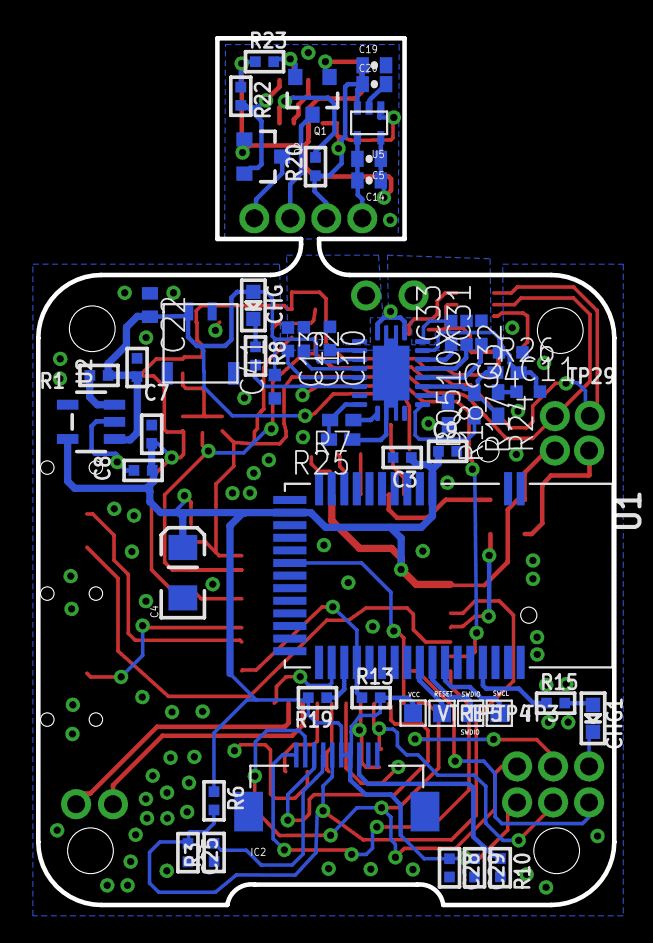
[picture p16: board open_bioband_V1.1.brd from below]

Board: 2 copper layers, 32.0 x 48.1 mm, 100 parts (55 on the bottom side), 58 nets.

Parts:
BQ510X: BQ24120; R-PQFP-N20
C1, C2, C5, C15, C17, C18, C20, C23, C24: 0.1uF; 0402-CAP
C3, C7, C9: 1uF; _0402
C4, C16: 10uF; EIA3216
C6, C8: 10µF; _0402
C10, C33: 0.01uF; C0402_LIBELIUM
C11, C41: 4.7uF; C0402_LIBELIUM
C12, C32: 0.47uF; C0402_LIBELIUM
C13, C31, C34: 0.022uF; C0402_LIBELIUM
C14: 4.7uF; 0402-CAP
C19: 10uF; 0402-CAP
C22: 4.7uF; C0402
C25: 0.1µF; _0402
C28, C29: 1µF; _0402
CHG: ORANGE; CHIPLED_0603
CHG1: BLUE; CHIPLED_0603
IC2: LS013B4DN04; FPC_10PIN_52892-1095
MEGA1284: TQFP44
Q1, Q2: 200mA/50V; SOT23-3
R1, R2: 100k; _0402
R3, R6, R10: 10k; _0402
R4, R13, R19: 100K; _0402
R5, R9, R12, R14, R16, R20, R22, R23: 4.7K; _0402
R7: 2.43K; R0402_LIBELIUM
R8: 1K; _0402
R15: 1k; _0402
R17: 3.83K; R0402_LIBELIUM
R18: 10k; R0402_LIBELIUM
R24: 140; R0402_LIBELIUM
R25: 0; R0402_LIBELIUM
R26: 100k; R0402_LIBELIUM
SW1, SW2, SW3: TACT_SMD2
TP1, TP2, TP14, TP15: TESTPOINT_ROUND_1MM
TP3: SWCLK; TESTPOINT_PAD_1MM
TP4: SWDIO; TESTPOINT_PAD_1MM
TP5: FCTRST; TESTPOINT_PAD_1MM
TP8, TP10, TP11, TP12, TP13, TP16, TP17, TP22, TP23, TP24, TP25, TP26, TP27, TP28, TP29, TP30, TP31, TP32: 1X01_ROUND
U1: BLE_MODULE_RAYTAC_MDBT40
U2: AP2112-3.3; SOT23-5
U4: MAX30101; OLGA-14
U5: 1.8V/100mA; SC70
U6: ADXL345ORIG; LGA14
U7: TSL2561FN; FN-6
U8: BME280; BME280_LGA
U$3: DF57H; DF57H-2P
VTREF: FCTRST; TESTPOINT_PAD_1MM
Y2: RESONATORSMD; RESONATOR-SMD

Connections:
1.8V: C5.1, C14.1, Q1.1, Q2.1, R22.1, R23.1, U4.11, U5.5
5: MEGA1284.41, TP2.P$1
!CS: R14.2, U8.P$2
!INT: R20.2, U4.13
!RESET: MEGA1284.4, R16.2, TP8.1
+3V3: C2.1, C3.1, C4.A, C7.1, C8.1, C9.1, C15.1, C16.A, C17.1, C18.1, C23.1, C24.1, C28.1, C29.1, IC2.P$6, IC2.P$7, MEGA1284.5, MEGA1284.17, MEGA1284.27, MEGA1284.38, R5.1, R6.1, R9.1, R12.1, R13.2, R14.1, R16.1, R19.2, TP1.P$1, TP12.1, TP16.1, U1.3, U1.14, U2.5, U6.1, U6.6, U6.7, U7.1, U8.P$6, U8.P$8, VTREF.P$1
+3V31: C19.1, C20.1, R20.1, TP25.1, U4.9, U4.10, U5.1, U5.3
A2: MEGA1284.32, R2.2, R4.1
AC1: BQ510X.2, C10.1, C12.1, C13.1, TP10.1
AC2: BQ510X.19, C31.2, C32.1, C33.2, TP11.1
AREF: C1.1, MEGA1284.29
BOOT3: BQ510X.3, C10.2
CHG: BQ510X.7, MEGA1284.43, R8.2
CLMP2: BQ510X.16, C32.2
CONNECTED_LED: R15.1, U1.39
DISP: C25.1, IC2.P$5, MEGA1284.40, R6.2
EN: R1.2, U2.3
EXTCOMIN: IC2.P$4, R3.2
EXTMODE: IC2.P$8, R10.1
FCTRYRST_3V: TP5.P$1, U1.34
FOD: BQ510X.14, R17.1, R24.2, R26.1
GND: BQ510X.1, BQ510X.9, BQ510X.20, C1.2, C2.2, C3.2, C4.C, C6.2, C7.2, C8.2, C9.2, C11.1, C15.2, C16.C, C17.2, C18.2, C22.1, C23.2, C24.2, C25.2, C28.2, C29.2, C34.1, C41.1, CHG1.C, IC2.P$9, IC2.P$10, MEGA1284.6, MEGA1284.18, MEGA1284.28, MEGA1284.39, R3.1, R4.2, R7.2, R10.2, R18.2, R19.1, R24.1, R25.2, SW1.2, SW1.4, SW2.2, SW2.4, SW3.2, SW3.4, TP13.1, TP14.P$1, TP17.1, U1.1, U1.2, U1.13, U1.16, U1.25, U1.28, U1.42, U2.2, U6.2, U6.4, U6.5, U6.12, U7.3, U8.P$1, U8.P$7, U$3.P$2, U$3.P$3, U$3.P$4, Y2.2
GND1: C5.2, C14.2, C19.2, C20.2, TP24.1, U4.4, U4.12, U5.2, U5.4
LV_SCL: Q2.2, R22.2, U4.2
LV_SDA: Q1.2, R23.2, U4.3
MISO: MEGA1284.2, TP31.1, U1.18
MOSI: IC2.P$2, MEGA1284.1, TP32.1
unnamed: CHG.C, R8.1
unnamed: MEGA1284.7, Y2.1
unnamed: CHG1.A, R15.2
unnamed: MEGA1284.8, Y2.3
unnamed: BQ510X.6, C13.2
unnamed: BQ510X.5, C12.2
unnamed: BQ510X.10, R7.1
unnamed: BQ510X.17, C33.1
unnamed: BQ510X.18, C11.2, C34.2, R26.2
unnamed: BQ510X.15, C31.1
unnamed: BQ510X.12, R17.2
unnamed: BQ510X.E@1, BQ510X.E@2, BQ510X.E@3, BQ510X.E@4, R25.1
NAV_DOWN: MEGA1284.15, SW3.3
NAV_SEL: MEGA1284.42, SW2.3
NAV_UP: MEGA1284.14, SW1.1
OUT: BQ510X.4, C6.1, C22.2, C41.2, CHG.A, R1.1, R2.1, U2.1, U$3.P$1
P0.5: BQ510X.13, R18.1
RX: MEGA1284.9, TP26.1
RX1: MEGA1284.11, U1.27
SCL: MEGA1284.19, R5.2, TP29.1, U6.14, U7.4, U8.P$4
SCL1: Q2.3, TP23.1
SCLK: IC2.P$1, MEGA1284.44
SCS: IC2.P$3, MEGA1284.3, TP30.1
SDA: MEGA1284.20, R9.2, TP28.1, U6.13, U7.6, U8.P$3
SDA1: Q1.3, TP22.1
SDO/ADR: R12.2, U8.P$5
SWCLK: TP3.P$1, U1.36
SWDIO/RST_3V: TP4.P$1, U1.35
S_TEMP: MEGA1284.31, TP15.P$1
TX: MEGA1284.10, TP27.1
TX1: MEGA1284.12, R13.1, U1.29

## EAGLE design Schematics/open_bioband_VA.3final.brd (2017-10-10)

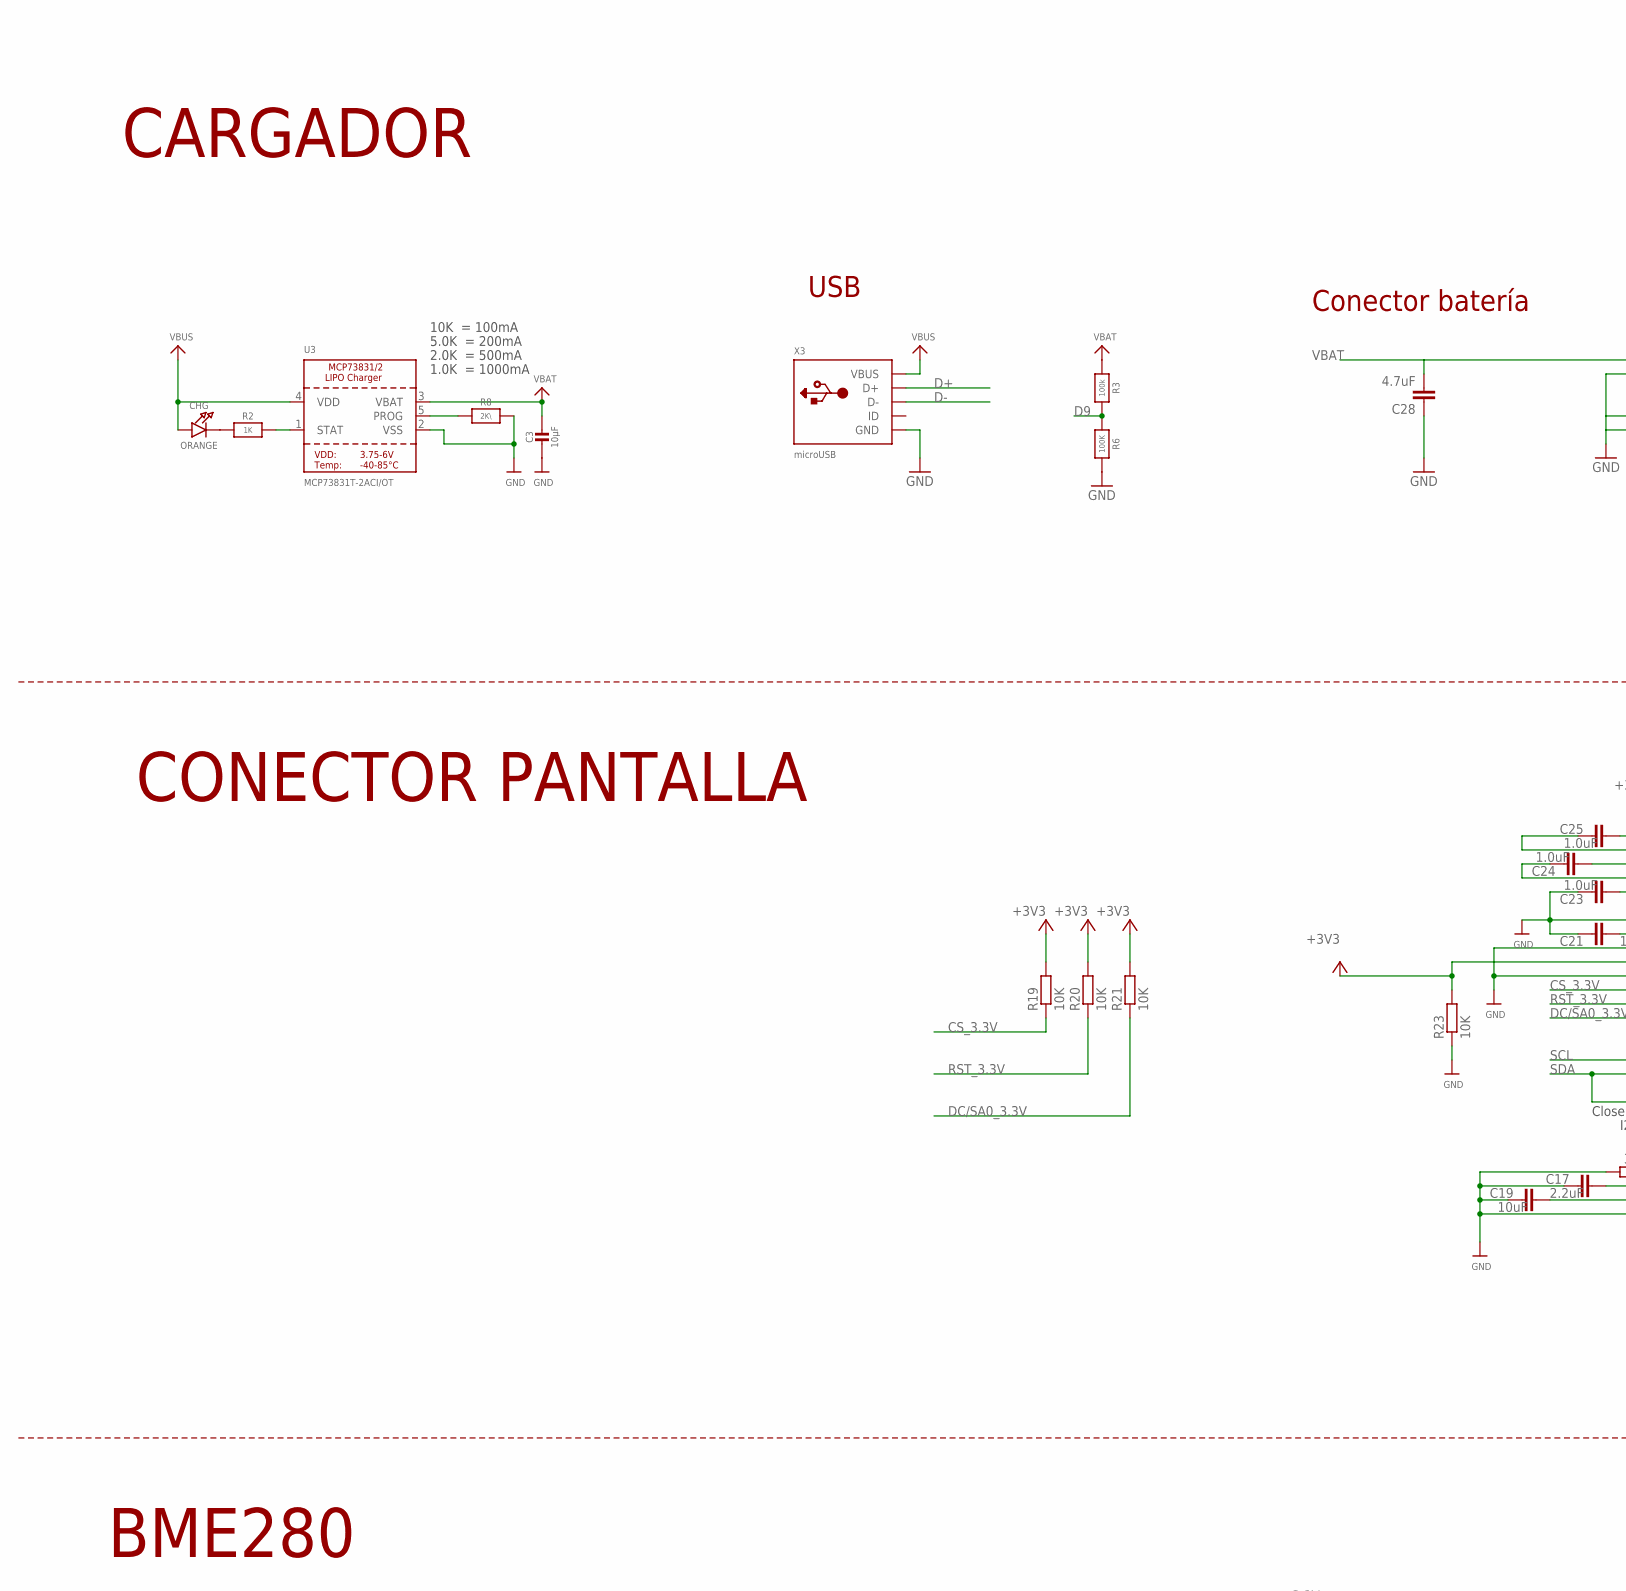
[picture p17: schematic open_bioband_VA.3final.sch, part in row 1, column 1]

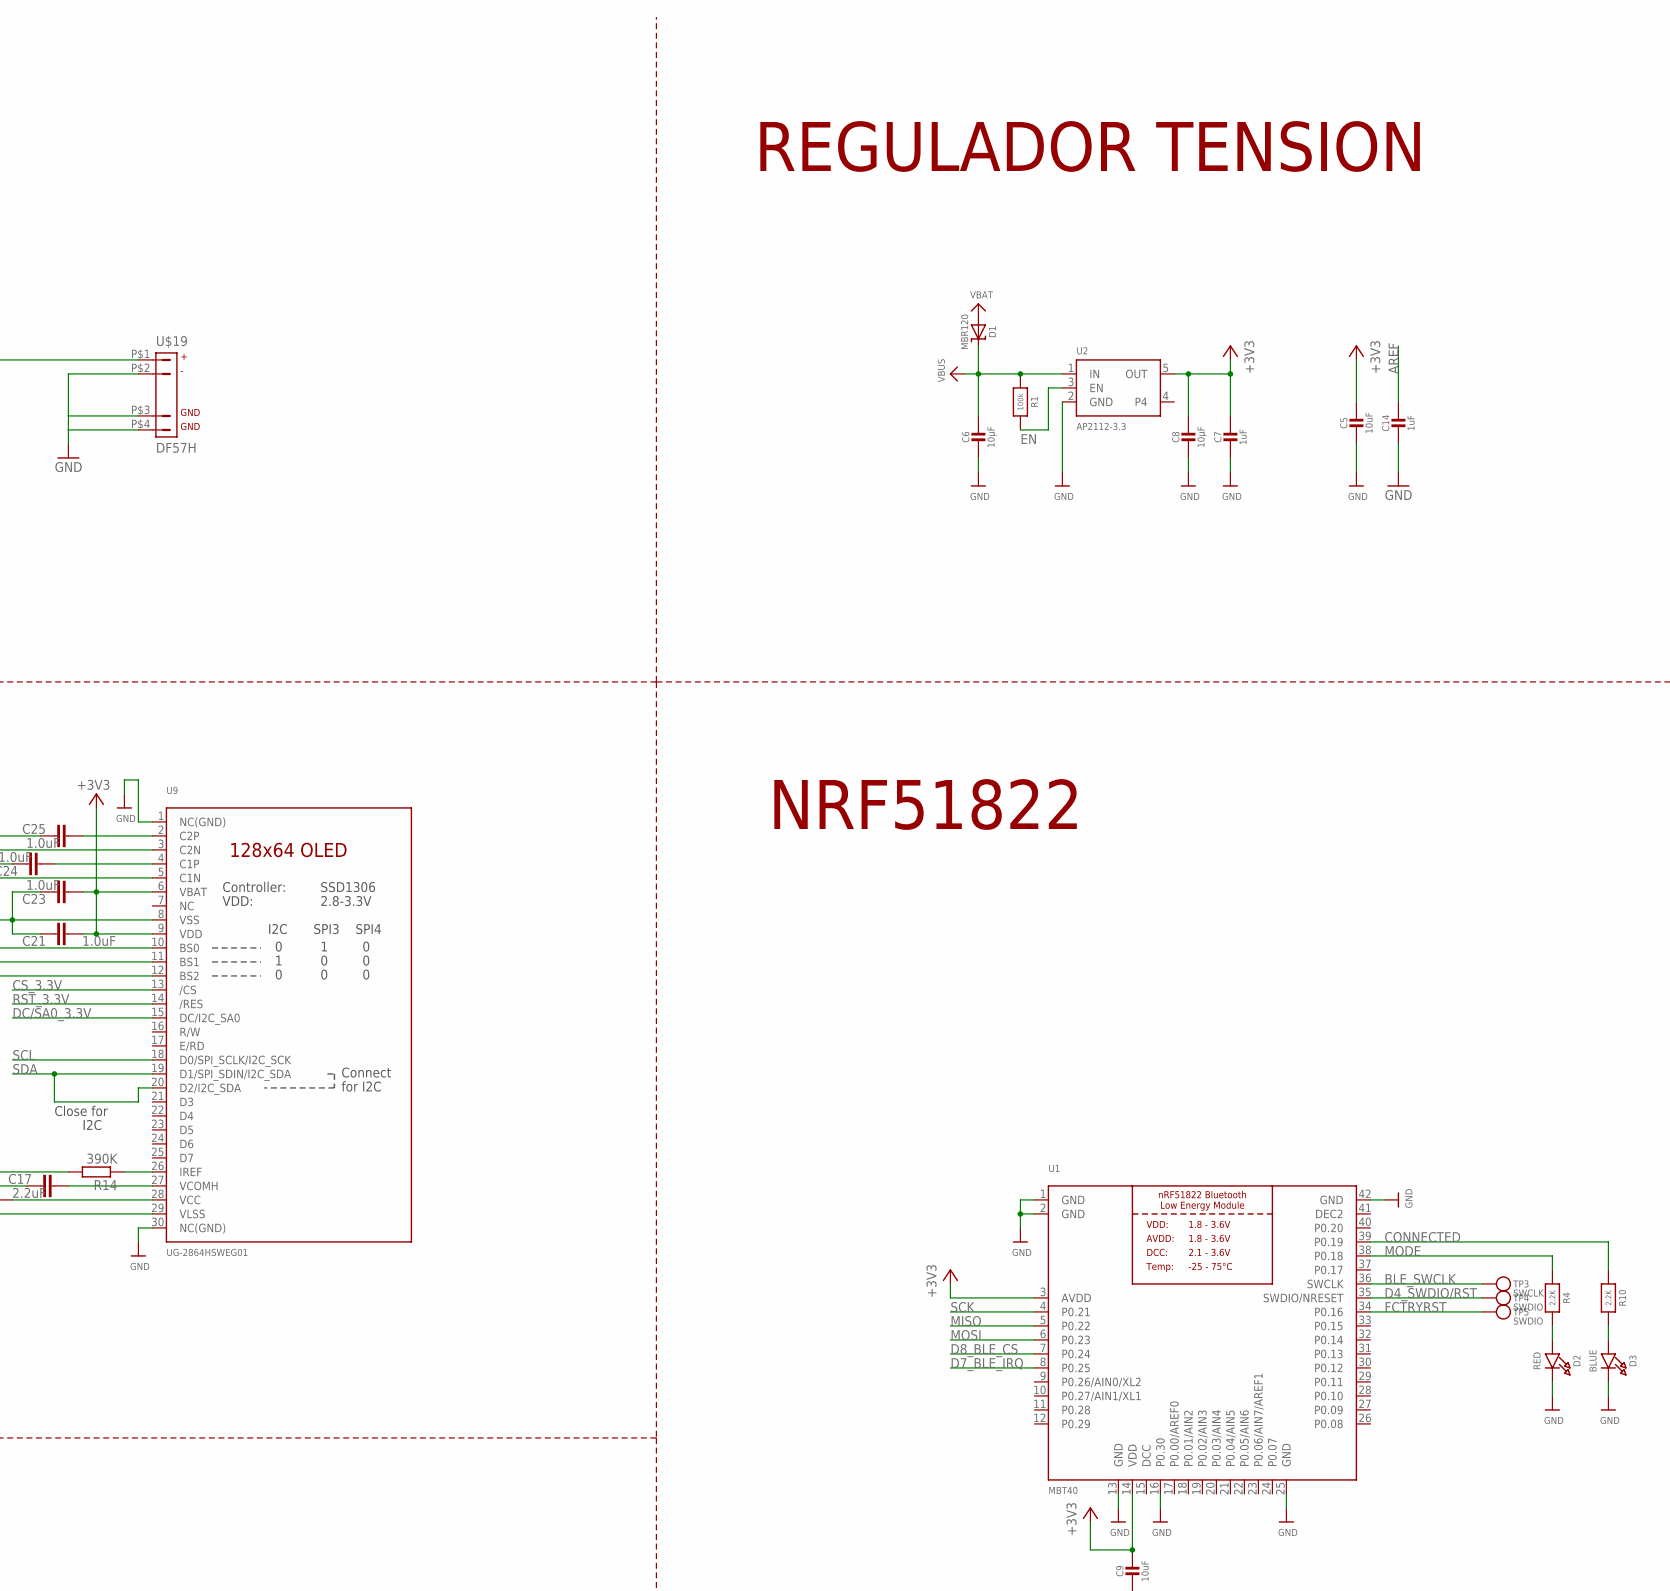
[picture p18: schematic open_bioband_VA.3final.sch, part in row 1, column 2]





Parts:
C1, C7, C14: 1uF; _0402
C2, C4: 22pF; _0402
C3, C6, C8: 10µF; _0402
C5, C9: 10uF; _0402
C10, C15, C18, C20: 0.1uF; 0402-CAP
C11: 4.7uF; 0402-CAP
C12: 10uF; 0402-CAP
C16: 10uF; EIA3216
C17: 2.2uF; 0402
C19: 10uF; 0402
C21, C23, C24, C25: 1.0uF; 0402
C22, C29: 0.1µF; _0402
C26: 0.01u; C0402
C27: 0.1uF; 0402
C28: 4.7uF; C0402
CHG: ORANGE; CHIPLED_0603
D1: MBR120; SOD-123@1
D2: RED; CHIPLED_0603
D3: BLUE; CHIPLED_0603
Q1, Q2: 200mA/50V; SOT23-3
R1, R3: 100k; _0402
R2: 1K; _0402
R4, R10: 2.2K; _0402
R5, R9, R11, R12, R13: 4.7K; _0402
R6: 100K; _0402
R7, R15: 4.7K; R0402
R8: 2K\; _0402
R14: 390K; R0402
R16: 10K; _0402
R19, R20, R21, R23: 10K; R0402
SW_DOWN: B3U-3100PM
SW_MODE: B3U-3100PM
SW_UP: B3U-3100PM
TP1, TP2, TP7, TP8, TP9, TP13, TP14, TP15, TP16: TESTPOINTROUND1MM; TESTPOINT_ROUND_1MM
TP3: SWCLK; TESTPOINT_PAD_1MM
TP4, TP5: SWDIO; TESTPOINT_PAD_1MM
TP6, TP10, TP11, TP12: TESTPOINTROUND0.5MM; TESTPOINT_ROUND_0.5MM
TP17, TP18, TP19, TP20, TP21, TP22, TP23, TP24: TESTPOINT0.1"; 1X01_ROUND
TP25, TP26, TP27, TP28: TESTPOINTPAD2MM; TESTPOINT_PAD_2MM
U1: MBT40; BLE_MODULE_RAYTAC_MDBT40
U2: AP2112-3.3; SOT23-5
U3: MCP73831T-2ACI/OT; SOT23-5@1
U4: MAX30101; OLGA-14
U5: 1.8V/100mA; SC70
U6: ADXL345ORIG; LGA14
U8: TSL2561FN; FN-6
U9: UG-2864HSWEG01; UG-2864HSWEG01_0.96IN_WRAPAROUND
U10: LMT70LMT70; BGA4C40P2X2_77X77X50
U11: BME280; BME280_LGA
U$4: ATSAMD21G18_QFN; TQFN48_7MM
U$19: DF57H; DF57H-2P
X2: 32.768; XTAL3215
X3: microUSB; 4UCONN_20329_V2

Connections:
1.8V: C10.1, C11.1, Q1.1 (G), Q2.1 (G), R9.1, R11.1, U4.11 (VDD), U5.5 (OUT)
!CS1: R7.1, U11.P$2 (!CS)
!INT: R13.2, U4.13 (!INT)
!RESET: R16.2, TP8.P$1, U$4.40 (/RESET)
+3V3: C5.1, C7.1, C8.1, C9.1, C12.1, C15.1, C16.A (+), C18.1, C20.1, C21.2, C22.1, C23.2, C29.1, R5.1, R7.2, R12.1, R13.1, R15.2, R16.1, R19.2, R20.2, R21.2, R23.2, TP7.P$1, TP11.P$1, TP13.P$1, TP22.1, U1.3 (AVDD), U1.14 (VDD), U2.5 (OUT), U4.9 (VLED+), U4.10 (VLED+), U5.1 (IN), U5.3 (EN), U6.1 (VDD), U6.6 (VSS), U6.7 (CS), U8.1 (VDD), U9.6 (VBAT), U9.9 (VDD), U9.11 (BS1), U11.P$6 (VDDIO), U11.P$8 (VDD), U$4.6 (VDDA), U$4.17 (VDDIO), U$4.36 (VDDIO), U$4.44 (VDDIN)
A0: U$4.3 (PA02/EINT2/AIN0/Y0/VOUT)
A1: TP15.P$1, U$4.7 (PB08/I8/AIN2/SERCOM4.0)
A2: U$4.8 (PB09/I9/AIN3/SERCOM4.1)
A3: U$4.9 (PA04/EINT4/VREFB/AIN4/SERCOM0.0)
A4: U$4.10 (PA05/EINT5/AIN5/SERCOM0.1)
A5: U$4.47 (PB02/I2/AIN10/SERCOM5.0)
AREF: C14.1, U$4.4 (PA03/EINT3/VREFA/AIN1)
BLE_SWCLK: TP3.P$1, U1.36 (SWCLK)
CONNECTED: R10.1, U1.39 (P0.19)
CS_3.3V: R19.1, U9.13 (/CS)
D0: U$4.16 (PA11/I11/AIN19/SERCOM0+2.3/I2SF0)
D1: U$4.15 (PA10/I10/AIN18/SERCOM0+2.2/I2SCK)
D2: U$4.23 (PA14/I14/SERCOM2+4.2)
D3: U$4.14 (PA09/I2C/I9/AIN17/SERCOM0+2.1/I2SMC)
D4_SWDIO/RST: TP4.P$1, U1.35 (SWDIO/NRESET), U$4.13 (PA08/I2C/AIN16/SERCOM0+2.0/I2SD1)
D6: U$4.29 (PA20/I4/SERCOM3+5.2/I2SSC)
D7_BLE_IRQ: U1.8 (P0.25), U$4.30 (PA21/I5/SERCOM3+5.3/I2SFS0)
D8_BLE_CS: U1.7 (P0.24), U$4.11 (PA06/EINT6/AIN6/SERCOM0.2)
D9: R3.2, R6.1, TP16.P$1, U$4.12 (PA07/I7/AIN7/SERCOM0.3/I2SD0)
D+: U$4.34 (PA25/I13/SERCOM3+5.3/D+), X3.D+
D-: U$4.33 (PA24/I12/SERCOM3+5.2/D-), X3.D-
DC/SA0_3.3V: R21.1, U9.15 (DC/I2C_SA0)
DCC: U1.15 (DCC)
DEC2: U1.41 (DEC2)
EN: R1.2, U2.3 (EN)
FCTRYRST: TP5.P$1, U1.34 (P0.16)
GND: C1.2, C2.2, C3.2, C4.2, C5.2, C6.2, C7.2, C8.2, C9.2, C10.2, C11.2, C12.2, C14.2, C15.2, C16.C (-), C17.1, C18.2, C19.1, C20.2, C21.1, C22.2, C23.1, C28.1, C29.2, D2.C, D3.C, R6.2, R8.2, R14.2, R23.1, SW_DOWN.P$1, SW_MODE.P$1, SW_UP.P$1, TP9.P$1, TP12.P$1, TP14.P$1, TP21.1, U1.1 (GND), U1.2 (GND), U1.13 (GND), U1.16 (P0.30), U1.25 (GND), U1.42 (GND), U2.2 (GND), U3.2 (VSS), U4.4 (PGND), U4.12 (GND), U5.2 (GND), U5.4 (BP), U6.2 (GND), U6.4 (GND), U6.5 (GND), U6.12 (SDO), U8.3 (GND), U9.1 (NC(GND)), U9.8 (VSS), U9.10 (BS0), U9.12 (BS2), U9.29 (VLSS), U9.30 (NC(GND)), U11.P$1 (GND1), U11.P$7 (GND2), U$4.5 (GNDA), U$4.18 (GND), U$4.35 (GND), U$4.42 (GND), U$4.THERMAL (GND), U$19.P$2 (2), U$19.P$3 (5), U$19.P$4 (6), X3.BASE@1 (GND), X3.BASE@2 (GND), X3.GND, X3.SPRT@1 (GND), X3.SPRT@2 (GND), X3.SPRT@3 (GND), X3.SPRT@4 (GND)
GND1: C26.2, C27.2, TP18.1, TP26.P$1, U10.A1 (GND)
INT1: U6.8 (INT1), U$4.26 (PA17/I2C/I1/SERCOM1+3.1)
LV_SCL: Q2.2 (S), R9.2, U4.2 (SCL)
LV_SDA: Q1.2 (S), R11.2, U4.3 (SDA)
MISO: U1.5 (P0.22), U$4.21 (PA12/I12/I2C/SERCOM2+4.0)
MODE: R4.1, U1.38 (P0.18)
MOSI: U1.6 (P0.23), U$4.19 (PB10/I10/SERCOM4.2/I2SMC)
unnamed: CHG.C, R2.1
unnamed: R2.2, U3.1 (STAT)
unnamed: R8.1, U3.5 (PROG)
unnamed: C2.1, U$4.1 (PA00/EINT0/SERCOM1.0), X2.P$1
unnamed: D2.A, R4.2
unnamed: C4.1, U$4.2 (PA01/EINT1/SERCOM1.1), X2.P$2
unnamed: D3.A, R10.2
unnamed: R14.1, U9.26 (IREF)
unnamed: C25.2, U9.2 (C2P)
unnamed: C25.1, U9.3 (C2N)
unnamed: C24.2, U9.4 (C1P)
unnamed: C24.1, U9.5 (C1N)
unnamed: C19.2, U9.28 (VCC)
unnamed: C17.2, U9.27 (VCOMH)
NAV_DOWN: SW_DOWN.P$2, U$4.28 (PA19/I3/SERCOM1+3.3/I2SD0)
NAV_SEL: SW_MODE.P$2, U$4.27 (PA18/I2/SERCOM1+3.2)
NAV_UP: SW_UP.P$2, U$4.25 (PA16/I2C/I0/SERCOM1+3.0)
RST_3.3V: R20.1, U9.14 (/RES), U$4.24 (PA15/I15/SERCOM3+4.3)
SCK: U1.4 (P0.21), U$4.20 (PB11/I11/SERCOM4.3/I2SCL)
SCL: Q2.3 (D), R5.2, TP10.P$1, TP24.1, U6.14 (SCL), U8.4 (SCL), U9.18 (D0/SPI_SCLK/I2C_SCK), U11.P$4 (SCK/SCL), U$4.32 (PA23/I2C/I7/SERCOM3+5.1/SOF)
SDA: Q1.3 (D), R12.2, TP6.P$1, TP23.1, U6.13 (SDA), U8.6 (SDA), U9.19 (D1/SPI_SDIN/I2C_SDA), U9.20 (D2/I2C_SDA), U11.P$3 (SDI/SDA), U$4.31 (PA22/I2C/I6/SERCOM3+5.0)
SDO/ADR1: R15.1, U11.P$5 (SDO/ADR)
SWCLK: TP1.P$1, U$4.45 (PA30/I10/SECOM1.2/SWCLK)
SWDIO: TP2.P$1, U$4.46 (PA31/I11/SECOM1.3/SWDIO)
TAO: C26.1, TP19.1, TP27.P$1, U10.B1 (TAO)
T_ON: TP20.1, TP28.P$1, U10.B2 (T_ON)
V3: C27.1, TP17.1, TP25.P$1, U10.A2 (VCC)
VBAT: C3.1, C28.2, D1.A, R3.1, U3.3 (VBAT), U$19.P$1 (1)
VBUS: C6.1, CHG.A, D1.C, R1.1, U2.1 (IN), U3.4 (VDD), X3.VBUS
VDDCORE: C1.1, U$4.43 (VDDCORE)

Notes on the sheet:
10K = 100mA
5.0K = 200mA
2.0K = 500mA
1.0K = 1000mA
N/C
TXLED
USBHOSTEN
RXLED
TXD
RXD
ATSAMD21
Close for
I2C
LMT70
Conector batería
Open BioBand
Proyecto Final de Carrera - EINA
Cortex M0
CARGADOR
REGULADOR TENSION
CONECTOR PANTALLA
NRF51822
BME280
TSL2561
ADXL345
MAX30101
PULSADORES
USB



Board: 2 copper layers, 36.6 x 65.1 mm, 99 parts (19 on the bottom side), 57 nets.

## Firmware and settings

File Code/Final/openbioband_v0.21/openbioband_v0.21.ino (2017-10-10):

/*
    Open BioBand is a biometric Open Source wristband with BLE (Bluetooth
    Low Energy) connectivity used to non-invasive monitorization of patients
    and their environment. It measure several parameters such as pulse, SPO2,
    body temperature, motion activity, pressure, humidity, temperature...

    It allow developers to investigate an learn about wereables and biometric
    sensors and artists to create new biological performances and projects.

    Created as final thesis Industrial Engineering project.

    This firmware manage all the circuits and sensors integrated in Open BioBand.
    Created by Esther Borao Moros, September 1, 2017.

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
    Version:                  0.15
    Implementation:           Esther Borao Moros
*/

/*******************************************************************************
   Includes
 *******************************************************************************/

// Librerías generales Arduino
#include <Wire.h>
#include <SPI.h>
#include <Arduino.h>
#include <SoftwareSerial.h>

// Librería interrupciones
#include "PinChangeInterrupt.h"

// Librerías sensor parámetros ambientales BME280
#include <stdint.h>
#include "SparkFunBME280.h"

// Librerías sensor acelerómetro ADXL345
#include <SparkFun_ADXL345.h>
#include "pedometer.h"

// Librería sensor luz TSL2561
#include <SparkFunTSL2561.h>

// Librerías pantalla SharpMem
#include <Adafruit_GFX.h>
#include <Adafruit_SharpMem.h>

// Librería bajo consumo
#include <LowPower.h>

// Librería pulsadores
#include <Button.h>

// Librerías sensor biométrico MAX30105
#include "MAX30105.h"
#include "HeartRate.h"
#include "spo2_algorithm.h"

// Librerías módulo BLE MDBT40 (nRF51822)
#include "Adafruit_BLE.h"
#include "Adafruit_BluefruitLE_UART.h"

/*******************************************************************************/


/*******************************************************************************
   Defines y variables
 *******************************************************************************/

/*****************************************************************************
  Modo Debug: descomentar el siguiente comentario para activar el modo.
******************************************************************************/

//#define BIOBAND_DEBUG

// Define en que salida se imprime el Modo Debug
#define DEBUG_SERIAL Serial

// Configuración Modo Debug
#ifdef BIOBAND_DEBUG
#define DEBUG_PRINT(...) { DEBUG_DEBUG_PRINT(__VA_ARGS__); }
#define DEBUG_PRINTLN(...) { DEBUG_SERIAL.println(__VA_ARGS__); }
#else
#define DEBUG_PRINT(...) {}
#define DEBUG_PRINTLN(...) {}
#endif

/*****************************************************************************/

// Control módulo BLE MDBT40 (nRF51822)
#define LONGITUDBUFFER                 128   // Tamaño del buffer de recepción de datos
#define MODO_VERBOSE                   true  // Con valor "true" se activa el modo debug 
#define MODO_UART_PIN                  -1    // Pin de control de modo, a "-1

#define RESET_FABRICA_HABILITADO         1
#define VERSION_MINIMA_FIRMWARE    "0.6.6"
#define MODO_LED_AVISO          "MODE"

Adafruit_BluefruitLE_UART ble(Serial1, MODO_UART_PIN);

int datoRecibido;

// Control pantalla SharpMem
#define SCK 10
#define MOSI 11
#define SS 13

Adafruit_SharpMem display(SCK, MOSI, SS);

#define NEGRO 0
#define BLANCO 1

// Control pulsadores
#define MBOT 6
#define UBOT 9
#define DBOT 8

// Control batería
#define VBATPIN A2
#define CHGPIN 7

int porcentajeBateria = 0;
int estadoBateria;

// Control iluminación
#define ILUMINACION 1

byte menuIluminacion = 1;
byte estadoIluminacion = 3;
double lux;

// Control sensor temperatura
#define LMT70_TAO A1
#define LMT70_TON 5

float LMT70_AMul = -0.000000001809628;
float LMT70_BMul = -0.000003325395;
float LMT70_CMul = -0.1814103;
float LMT70_DMul = 205.5894;

// Control pulsadores
Button botonCentral(MBOT, true, true, 20);
Button botonArriba(UBOT, true, true, 20);
Button botonAbajo(DBOT, true, true, 20);

// Control sensor biométrico MAX30105
#define BRILLO_MAXIMO 255

MAX30105 sensorBiometrico;

#define MAX_BRIGHTNESS 255

const byte RATE_SIZE = 4; //Increase this for more averaging. 4 is good.
byte rates[RATE_SIZE]; //Array of heart rates
byte rateSpot = 0;
long lastBeat = 0; //Time at which the last beat occurred

float beatsPerMinute;
int beatAvg;

int counterSPO2;
int spoRandom;

float tempera;
// Control sensor parámetros ambientales BME280
BME280 sensorAmbiente;

float temperatura;
float presion;
float altitud;
float humedad;

// Control sensor luz TSL2561
SFE_TSL2561 sensorLuz;

boolean gananciaLuz;
unsigned int ms;

// Control navegación pantallas
unsigned long tiempoStandby;
byte tiempoActivo = 15;
boolean active = false;

byte paginaActual = 0;
byte menuVal = 0;
byte configVal = 0;

boolean flicker = false;
unsigned long paradaRelojTimer = 0;
boolean paradaRelojActivo = false;
unsigned long paradaRelojMs = 0;

// Control sensor batería
boolean visualizacionVoltaje = true;

// Control reloj
int u_hora = 0;
int u_minuto = 0;
int u_segundo = 0;
int d_hora = 0;
int d_minuto = 0;
int d_segundo = 0;
unsigned long timer1 = 0;
unsigned long timer2 = 0;

// Control sensor acelerómetro ADXL345
Pedometer acelerometro;

int peso = 50;    //kg
int altura = 160; //cm
float long_paso;
float calorias_milla;
float pasos_milla;
float calorias_quemadas;
float distancia;
float factor;

/*******************************************************************************/


/*******************************************************************************
   Inicialización
 *******************************************************************************/

void setup(void) {

  // Configuración puertos serie
 // Serial.begin(9600);
 tempera=20;

  // Configuración batería
  pinMode(CHGPIN, INPUT_PULLUP);
  //attachPCINT(digitalPinToPCINT(CHGPIN), despertarMicro, FALLING);

  // Configuración sensor luz TSL2561
  pinMode(ILUMINACION, OUTPUT);

  // Configuración sensor acelerómetro ADXL345
  acelerometro.init();

  // Configuración sensor biométrico MAX30105
  if (!sensorBiometrico.begin(Wire, I2C_SPEED_FAST))
  {
    DEBUG_PRINT("MAX30101 no fue encontrado. ");
    DEBUG_PRINTLN("Comprueba el cableado o la alimentacion ");
    while (1);
  }

  sensorBiometrico.setup(); //Configure sensor with default settings
  sensorBiometrico.setPulseAmplitudeRed(0x0A); //Turn Red LED to low to indicate sensor is running
  sensorBiometrico.setPulseAmplitudeGreen(0); //Turn off Green LED

  // Configuración sensor luz TSL2561
  unsigned char ID;
  gananciaLuz = 0;
  unsigned char tiempoLuz = 2;

  sensorLuz.begin();
  sensorLuz.getID(ID);
  sensorLuz.setTiming(gananciaLuz, tiempoLuz, ms);
  sensorLuz.setPowerUp();

  // Configuración y calibración sensor parámetros ambientales BME280
  sensorAmbiente.settings.commInterface = I2C_MODE;
  sensorAmbiente.settings.I2CAddress = 0x77;
  sensorAmbiente.settings.runMode = 3; // Modo Normal
  sensorAmbiente.settings.tStandby = 0; // Tiempo de Standby
  sensorAmbiente.settings.filter = 0;
  sensorAmbiente.settings.tempOverSample = 1;
  sensorAmbiente.settings.pressOverSample = 1;
  sensorAmbiente.settings.humidOverSample = 1;

  delay(10);  //Requiere 2ms para empezar
  sensorAmbiente.begin();
  sensorAmbiente.readRegister(BME280_CHIP_ID_REG);
  sensorAmbiente.readRegister(BME280_RST_REG);
  sensorAmbiente.readRegister(BME280_CTRL_MEAS_REG);
  sensorAmbiente.readRegister(BME280_CTRL_HUMIDITY_REG);

  uint8_t contadorMem = 0x80;
  uint8_t lecturaDatoTemp;

  for (int rowi = 8; rowi < 16; rowi++ )
  {
    DEBUG_PRINT("0x");
    DEBUG_PRINT(rowi, HEX);
    DEBUG_PRINT("0:");
    for (int coli = 0; coli < 16; coli++ )
    {
      lecturaDatoTemp = sensorAmbiente.readRegister(contadorMem);
      DEBUG_PRINT((lecturaDatoTemp >> 4) & 0x0F, HEX);// Imprimir primera parte en hexadecimal
      DEBUG_PRINT(lecturaDatoTemp & 0x0F, HEX);// Imprimir segunda parte en hexadecimal
      DEBUG_PRINT(" ");
      contadorMem++;
    }
    DEBUG_PRINT("\n");
  }

  sensorAmbiente.calibration.dig_T1;
  sensorAmbiente.calibration.dig_T2;
  sensorAmbiente.calibration.dig_T3;

  sensorAmbiente.calibration.dig_P1;
  sensorAmbiente.calibration.dig_P2;
  sensorAmbiente.calibration.dig_P3;
  sensorAmbiente.calibration.dig_P4;
  sensorAmbiente.calibration.dig_P5;
  sensorAmbiente.calibration.dig_P6;
  sensorAmbiente.calibration.dig_P7;
  sensorAmbiente.calibration.dig_P8;
  sensorAmbiente.calibration.dig_P9;

  sensorAmbiente.calibration.dig_H1;
  sensorAmbiente.calibration.dig_H2;
  sensorAmbiente.calibration.dig_H3;
  sensorAmbiente.calibration.dig_H4;
  sensorAmbiente.calibration.dig_H5;
  sensorAmbiente.calibration.dig_H6;

  // Configuración pantalla SharpMem
  display.begin();
  display.setRotation(0);
  display.clearDisplay();

  display.setCursor(52, 4);
  display.setTextColor(NEGRO, BLANCO);
  display.print("porcentajeBateria");


  // Configuración sensor temperatura
  pinMode(LMT70_TON, OUTPUT);

  // Configuración pulsadores
  pinMode(MBOT, INPUT_PULLUP);
  pinMode(UBOT, INPUT_PULLUP);
  pinMode(DBOT, INPUT_PULLUP);

  attachInterrupt(2, despertarMicro, FALLING);

  botonCentral.read();
  botonArriba.read();
  botonAbajo.read();

  // Configuración módulo BLE MDBT40 (nRF51822)
  if ( !ble.begin(MODO_VERBOSE) ) {
    error(F("No se puede conectar con el módulo"));
  }
  DEBUG_PRINTLN( F("Conexion correcta") );

  if ( RESET_FABRICA_HABILITADO ) {
    // Reset de fábrica para inicializar los valores
    DEBUG_PRINTLN(F("Reset de fabrica: "));
    if ( ! ble.factoryReset() ) {
      error(F("No es posible el reseteo"));
    }
  }
  // Deshabilita el comando "echo"
  ble.echo(false);

  // Activación led de indicaciones
  ble.verbose(false);

  // Configura en modo DATA
  //ble.setMode(BLUEFRUIT_MODE_DATA);

  // Configuración e inicializacion actualización pantalla
  tiempoStandby = millis() + tiempoActivo * 1000;

}

/*******************************************************************************/


/*******************************************************************************
   Bucle Principal
 *******************************************************************************/

void loop(void) {

  // Comprobación estado carga batería
  int carga = digitalRead(CHGPIN);

  // Comprobación si está activa la navegación
  active = (millis() <= tiempoStandby);

  //  // Comprobación conexión módulo BLE MDBT40 (nRF51822)
  //  if (ble.isConnected()) {
  //    ble.print("AT+BLEUARTTX=");
  //    ble.println("Connected");
  //    // Comprobación de envío correcto de comando
  //    if (! ble.waitForOK() ) {
  //      DEBUG_PRINTLN(F("Fallo al enviar"));
  //    }
  //
  //    // Comprobación de datos entrantes
  //    ble.println("AT+BLEUARTRX");
  //    ble.readline();
  //    if (strcmp(ble.buffer, "OK") == 0) {
  //      return;
  //    }
  //
  //    // Datos recibidos. Almacenados en el buffer
  //    DEBUG_PRINT(F("[Recv] "));
  //    DEBUG_PRINTLN(ble.buffer);
  //    ble.waitForOK();
  //  }

  // Lectura botón central
  botonCentral.read();

  // Reseteo del Timer de actualización de pantalla si se detecta pulsación
  if (active && (botonArriba.read() || botonAbajo.read()))
  {
    tiempoStandby = millis() + tiempoActivo * 1000;
  }

  // Comprobación finalización navegación pantallas y reinicio
  if (paginaActual == 0 && botonCentral.wasPressed()) {
    paginaActual = 10;
    menuVal = 0;
    botonCentral.read();
  }

  // Conteo de segundos
  un_seg ();

  // Actualización reloj
  contador();

  // Actualización navegación pantallas
  if (paginaActual == 0 || !active) pantallaPrincipal();
  else if (paginaActual == 10) pantallaMenu();
  else if (paginaActual == 1) pantallaSalud();
  else if (paginaActual == 2) pantallaAmbiente();
  else if (paginaActual == 3) pantallaMovimiento();
  else if (paginaActual == 4) pantallaCronometro();
  else if (paginaActual == 5) pantallaAjustes();
  else if (paginaActual == 6) pantallaJuego();
  else if (paginaActual == 7) pantallaIluminacion();
  else if (paginaActual == 8) pantallaReloj();
  else if (paginaActual == 9) pantallaNotificaciones();
  else display.clearDisplay();

  // Medición sensor luz TSL2561
  unsigned int data0, data1;

  sensorLuz.getData(data0, data1);
  sensorLuz.getLux(gananciaLuz, ms, data0, data1, lux);

  // Comprobación estado iluminación
  switch (estadoIluminacion) {
    case 1:
      if (lux < 0.05) {
        digitalWrite(ILUMINACION, HIGH);
      }
      if (lux> 4.0){ digitalWrite(ILUMINACION, LOW);}
      //else  digitalWrite(ILUMINACION, HIGH);
      break;
    case 2:
      digitalWrite(ILUMINACION, HIGH);
      break;
    case 3:
      digitalWrite(ILUMINACION, LOW);
      break;
  }

  // Refresco pantalla
  display.refresh();

  // Comprobación tiempo Stanby y activación modo bajo consumo
  if (!active) {
    paginaActual = 0;
    LowPower.powerDown(SLEEP_FOREVER, ADC_OFF, BOD_OFF);
  }
  else if (!flicker) digitalWrite(SCK, HIGH); // Elimina error por "flicker"

}

/*******************************************************************************/


/*******************************************************************************
   Otras funciones
 *******************************************************************************/

//!****************************************************************************
//!   Nombre: despertarMicro
//!   Descripción: Despierta el microcontrolador del modo de bajo consumo
//!   Parámetro entrada: void
//!   Parámetro salida: void
//!   Ejemplo: despertarMicro();
//!****************************************************************************

void despertarMicro() {

  noInterrupts();
  tiempoStandby = millis() + tiempoActivo * 1000; // Resetea Timer Standby
  interrupts();
}

/*****************************************************************************/

//!****************************************************************************
//!   Nombre: un_seg
//!   Descripción: Rutina para el conteo de segundos
//!   Parámetro entrada: void
//!   Parámetro salida: void
//!   Ejemplo: un_seg();
//!****************************************************************************

//Reloj
void un_seg() {

  //Rutina para cada segundo
  timer2 = (millis() / 1000);
  if ( timer1 != timer2 ) {
    timer1 = timer2;
    u_segundo++;
  }
}
/*****************************************************************************/


//!****************************************************************************
//!   Nombre: contador
//!   Descripción: Rutina que lleva el conteo del reloj
//!   Parámetro entrada: void
//!   Parámetro salida: void
//!   Ejemplo: contador();
//!****************************************************************************

void contador() {

  // Rutina de segundos
  if ( u_segundo == 10 ) {
    u_segundo = 0;
    d_segundo++;
  }
  if ( ( d_segundo == 6 ) && ( u_segundo == 0 ) ) {
    d_segundo = 0;
    u_minuto++;
  }

  // Rutina de minutos
  if ( u_minuto == 10 ) {
    u_minuto = 0;
    d_minuto++;
  }
  if ( ( d_minuto == 6 ) && ( u_minuto == 0 ) ) {
    d_minuto = 0;
    u_hora++;
  }

  // Rutina de horas
  if ( u_hora == 10 ) {
    u_hora = 0;
    d_hora++;
  }
  if ( (d_hora == 2) &&  (u_hora == 4) ) {
    u_hora = 0;
    d_hora = 0;
  }
}

/*****************************************************************************/


//!****************************************************************************
//!   Nombre: dibujarDigito
//!   Descripción: Dibuja en la pantalla un dígito
//!   Parámetro entrada: int posición X, int posición Y, int dígito, bool color
//!   Parámetro salida: void
//!   Ejemplo: dibujarDigito(10,20,7,1);
//!****************************************************************************

void dibujarDigito(int posX, int posY, int digito, boolean col) {

  switch (digito) {
    case 0:
      display.fillRect(posX, posY, 20, 8, col);
      display.fillRect(posX, posY, 7, 40, col);
      display.fillRect(posX + 13, posY, 7, 40, col);
      display.fillRect(posX, posY + 32, 20, 8, col);
      break;
    case 1:
      display.fillRect(posX + 13, posY, 7, 40, col);
      break;
    case 2:
      display.fillRect(posX, posY, 20, 8, col);
      display.fillRect(posX, posY + 16, 20, 8, col);
      display.fillRect(posX, posY + 24, 7, 8, col);
      display.fillRect(posX + 13, posY, 7, 16, col);
      display.fillRect(posX, posY + 32, 20, 8, col);
      break;
    case 3:
      display.fillRect(posX, posY, 20, 8, col);
      display.fillRect(posX, posY + 16, 20, 8, col);
      display.fillRect(posX + 13, posY, 7, 40, col);
      display.fillRect(posX, posY + 32, 20, 8, col);
      break;
    case 4:
      display.fillRect(posX, posY, 7, 16, col);
      display.fillRect(posX, posY + 16, 20, 8, col);
      display.fillRect(posX + 13, posY, 7, 40, col);
      break;
    case 5:
      display.fillRect(posX, posY, 20, 8, col);
      display.fillRect(posX, posY + 16, 20, 8, col);
      display.fillRect(posX + 13, posY + 24, 7, 8, col);
      display.fillRect(posX, posY, 7, 16, col);
      display.fillRect(posX, posY + 32, 20, 8, col);
      break;
    case 6:
      display.fillRect(posX, posY, 20, 8, col);
      display.fillRect(posX, posY + 16, 20, 8, col);
      display.fillRect(posX + 13, posY + 24, 7, 8, col);
      display.fillRect(posX, posY, 7, 40, col);
      display.fillRect(posX, posY + 32, 20, 8, col);
      break;
    case 7:
      display.fillRect(posX, posY, 20, 8, col);
      display.fillRect(posX + 13, posY, 7, 40, col);
      break;
    case 8:
      display.fillRect(posX, posY, 20, 8, col);
      display.fillRect(posX, posY, 7, 40, col);
      display.fillRect(posX, posY + 16, 20, 8, col);
      display.fillRect(posX + 13, posY, 7, 40, col);
      display.fillRect(posX, posY + 32, 20, 8, col);
      break;
    case 9:
      display.fillRect(posX, posY, 20, 8, col);
      display.fillRect(posX, posY, 7, 16, col);
      display.fillRect(posX, posY + 16, 20, 8, col);
      display.fillRect(posX + 13, posY, 7, 40, col);
      display.fillRect(posX, posY + 32, 20, 8, col);
      break;
  }
}

/*****************************************************************************/


//!****************************************************************************
//!   Nombre: error
//!   Descripción: Imprime el error de inicialización del módulo BLE
//!   Parámetro entrada: cost Respuesta del módulo tras inicialización
//!   Parámetro salida: void
//!   Ejemplo: error(FlashStringHelper);
//!****************************************************************************

//Control inicialización BLE (Bluetooth Low Energy)
void error(const __FlashStringHelper*err) {

  DEBUG_PRINT(err);
  //while (1);
}

/*****************************************************************************/


//!****************************************************************************
//!   Nombre: leerVoltage
//!   Descripción: Lee el valor de la batería Vcc y lo transforma en mv
//!   Parámetro entrada: void
//!   Parámetro salida: long valor en mv de la batería
//!   Ejemplo: leerVoltage();
//!****************************************************************************

long leerVoltage() {

  int resultado;
  float voltageMedido = analogRead(VBATPIN);
  voltageMedido *= 2;    // Multiplica por 2
  voltageMedido *= 3.3;  // Multiplica por 3.3, la referencia de tensión
  voltageMedido /= 1024; // Convierte en tensión
  DEBUG_PRINT("VBat: " ); DEBUG_PRINTLN(voltageMedido);

  resultado = voltageMedido * 1000; // Calcula Vcc (en mV); 1125300 = 1.1*1023*1000
  return resultado; // Devuelve Vcc en mV
}

/*****************************************************************************/

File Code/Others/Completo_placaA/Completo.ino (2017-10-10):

/*
    ADXL345 Triple Axis Accelerometer. Activity & Inactivity
    Read more: http://www.jarzebski.pl/arduino/czujniki-i-sensory/3-osiowy-akcelerometr-adxl345.html
    GIT: https://github.com/jarzebski/Arduino-ADXL345
    Web: http://www.jarzebski.pl
    (c) 2014 by Korneliusz Jarzebski
*/
#include <SPI.h>
#include <Wire.h>

//Environment
#include <stdint.h>
#include "SparkFunBME280.h"

//Acc
#include <ADXL345.h>

//Screen
#include <Adafruit_GFX.h>
#include <Adafruit_SSD1306.h>

//Light sensor
#include <Adafruit_Sensor.h>
#include <Adafruit_TSL2561_U.h>

//Screen
#define OLED_RESET 0  // GPIO0
Adafruit_SSD1306 display(OLED_RESET);

#define NUMFLAKES 10
#define XPOS 0
#define YPOS 1
#define DELTAY 2
//////////

///Pulse
#include "MAX30105.h"

#include "heartRate.h"

MAX30105 particleSensor;

const byte RATE_SIZE = 4; //Increase this for more averaging. 4 is good.
byte rates[RATE_SIZE]; //Array of heart rates
byte rateSpot = 0;
long lastBeat = 0; //Time at which the last beat occurred
byte readLED = 13; //Blinks with each data read
float beatsPerMinute;
int beatAvg;
 byte ledBrightness = 60; //Options: 0=Off to 255=50mA
  byte sampleAverage = 4; //Options: 1, 2, 4, 8, 16, 32
  byte ledMode = 2; //Options: 1 = Red only, 2 = Red + IR, 3 = Red + IR + Green
  byte sampleRate = 100; //Options: 50, 100, 200, 400, 800, 1000, 1600, 3200
  int pulseWidth = 411; //Options: 69, 118, 215, 411
  int adcRange = 4096; //Options: 2048, 4096, 8192, 16384
  ///////////////////////

int steps,flag=0;

//Environment
BME280 mySensor;
float temperatura;
float presion;
float altitud;
float humedad;

//Acc
ADXL345 accelerometer;

//Buttons
int buttonPushCounter = 1;   // counter for the number of button presses
int buttonState5 = 0;         // current state of the button
int buttonState6 = 0;         // current state of the button
int lastButtonState = 0;     // previous state of the button

const int  buttonPin = 11;    // the pin that the Up pushbutton is attached to

const int  buttonPin1 = 12;    // the pin that the Down pushbutton is attached to

//Light
Adafruit_TSL2561_Unified tsl = Adafruit_TSL2561_Unified(TSL2561_ADDR_FLOAT, 12345);

void displaySensorDetails(void)
{
  sensor_t sensor;
  tsl.getSensor(&sensor);
  Serial.println("------------------------------------");
  Serial.print  ("Sensor:       "); Serial.println(sensor.name);
  Serial.print  ("Driver Ver:   "); Serial.println(sensor.version);
  Serial.print  ("Unique ID:    "); Serial.println(sensor.sensor_id);
  Serial.print  ("Max Value:    "); Serial.print(sensor.max_value); Serial.println(" lux");
  Serial.print  ("Min Value:    "); Serial.print(sensor.min_value); Serial.println(" lux");
  Serial.print  ("Resolution:   "); Serial.print(sensor.resolution); Serial.println(" lux");  
  Serial.println("------------------------------------");
  Serial.println("");
  delay(500);
}

/**************************************************************************/
/*
    Configures the gain and integration time for the TSL2561
*/
/**************************************************************************/
void configureSensor(void)
{
  /* You can also manually set the gain or enable auto-gain support */
  // tsl.setGain(TSL2561_GAIN_1X);      /* No gain ... use in bright light to avoid sensor saturation */
  // tsl.setGain(TSL2561_GAIN_16X);     /* 16x gain ... use in low light to boost sensitivity */
  tsl.enableAutoRange(true);            /* Auto-gain ... switches automatically between 1x and 16x */
  
  /* Changing the integration time gives you better sensor resolution (402ms = 16-bit data) */
  tsl.setIntegrationTime(TSL2561_INTEGRATIONTIME_13MS);      /* fast but low resolution */
  // tsl.setIntegrationTime(TSL2561_INTEGRATIONTIME_101MS);  /* medium resolution and speed   */
  // tsl.setIntegrationTime(TSL2561_INTEGRATIONTIME_402MS);  /* 16-bit data but slowest conversions */

  /* Update these values depending on what you've set above! */  
  Serial.println("------------------------------------");
  Serial.print  ("Gain:         "); Serial.println("Auto");
  Serial.print  ("Timing:       "); Serial.println("13 ms");
  Serial.println("------------------------------------");
}

//////////////////

void setup(void) 
{
  Serial.begin(9600);
  // Serial1.begin(9600);
    pinMode(buttonPin, INPUT);
   
   pinMode(buttonPin1, INPUT);
   
   //Pulse
   // Initialize sensor
  if (!particleSensor.begin(Wire, I2C_SPEED_FAST)) //Use default I2C port, 400kHz speed
  {
    Serial.println("MAX30105 was not found. Please check wiring/power. ");
    while (1);
  }
  Serial.println("Place your index finger on the sensor with steady pressure.");

  particleSensor.setup(); //Configure sensor with default settings
  particleSensor.setPulseAmplitudeRed(0x0A); //Turn Red LED to low to indicate sensor is running
  particleSensor.setPulseAmplitudeGreen(0); //Turn off Green LED
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

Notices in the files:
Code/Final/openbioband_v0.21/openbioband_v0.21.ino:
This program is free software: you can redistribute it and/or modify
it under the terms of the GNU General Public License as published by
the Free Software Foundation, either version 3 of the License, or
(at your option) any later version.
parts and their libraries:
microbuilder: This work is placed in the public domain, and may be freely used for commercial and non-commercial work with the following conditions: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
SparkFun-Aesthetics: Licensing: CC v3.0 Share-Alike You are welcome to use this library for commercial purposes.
